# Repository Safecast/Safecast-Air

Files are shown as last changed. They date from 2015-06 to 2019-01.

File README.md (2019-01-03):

# Safecast Air

Documentation for Safecast's Air Quality Monitoring device and platform.

Parts  
https://github.com/Safecast/Safecast-Air/wiki/Assembly-Manual#parts-list

Assembly Manual  
https://github.com/Safecast/Safecast-Air/wiki/Assembly-Manual

Operation Manual  
https://github.com/Safecast/Safecast-Air/wiki/Operations-Manual

Support  
https://groups.google.com/forum/#!forum/safecast-air

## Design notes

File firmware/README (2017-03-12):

You will need the following in order to update the firmware:  

Arduino IDE 1.8.0  
https://www.arduino.cc/en/Main/Software  
  
Teensy 1.3.4 (software for version 3.2)  
https://www.pjrc.com/teensy/teensyduino.html  
  
Firmware files  
https://github.com/Safecast/Safecast-Air/tree/master/firmware  
  
For the beta we are specifically using the files from /particulate_only  
  
Look in Arduino preferences and make sure that your Arduino sketchbook location is pointing at the 'firmware' folder on your local drive. Example:
/Users/yourname/Desktop/Safecast-Air-master/firmware/  After making this change to the Arduino IDE make sure to restart the Arduino IDE.  

Programing:

1. Using the Arduino IDE open the file named particulate_only.ino which is located in the firmware/particulate_only subdirectory.

2. Go to the "Tools -> Board:"  menu item and select the board type (Teensy 3.1/3.2).

3. Go to the "Tools -> USB Type:" menu item select the  USB type (Serial). 

4. Go to the "Tools -> CPU Speed:" menu item and select the CPU speed (72MHz)

5. Go to the "Tools -> Port:" menu item and select port associated with your teensy 3.2 device e.g. COM1 (windows) or  /dev/ttyACM0 (linux)

6. Build the firmware by selecting the "Sketch -> Verify/Compile" menu item (or the "check mark" menu icon).

7. Upload the firmware to your teensy 3.2 by selecting the "Sketch -> Upload" menu item (or the "right arrow" menu icon). 

Practice  
If you are new to updating Arduino, then please go through this quick tutorial. Start with "Install Arduino" and then practice with the Blink exercise. You will then apply this same logic to upload the Safecast files.
https://www.pjrc.com/teensy/tutorial.html

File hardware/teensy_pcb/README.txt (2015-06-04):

Temporary repository for development of the safecast air prototype.

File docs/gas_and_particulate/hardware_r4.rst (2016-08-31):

Bill of Materials
===================

**This is the BOM for prototype V0.1 R4**

====================  =====  =============================================   ===================     =======================         
Ref                   Qty    Description                                     Vendor                  Part #
====================  =====  =============================================   ===================     =======================         
R1-23 (odd) [#f1]_     12     68k resistor (0.1%)                             Digikey                 YAG1958CT-ND   
R2-24 (even) [#f1]_    12     20k resistor (0.1%)                             Digikey                 P20KDACT-ND
R25                     1     22 Ohm resistor (SM0805)                        Digikey                 RMCF0805JT22R0CT-ND
R26                     1     10K resistor (SM0805)                           Digikey                 311-10KARCT-ND
R27                     1     20k resistor (SM0805)                           Digikey                 311-20.0KCRCT-ND
R28                     1     12k resistor (SM0805)                           Digikey                 311-12KARCT-ND
R29, R30                2     4.7k resistor (select via I2C requirements)     Digikey                 311-4.70KCRCT-ND
C1                      1     0.1uf ceram. cap. (SMO805)                      Digikey                 311-1361-1-ND

P1, P2 [#f1]_           2     Mini shrouded header, 5x2                       Digikey                 WM18560-ND
P3                      1     Shrouded header, 5x2                            Digikey                 S9169-ND
P4, P11                 2     2x2 pin array                                   Digikey                 609-3225-ND                 
P5,7,8,10               4     Breakaway header, male pins, 36 pos             Digikey                 3M9457-ND
P6                      1     Screw terminal block, 2-pos                     Digikey                 ED2635-ND
P9                      1     6-pin JST XH connector                          Digikey                 455-2271-ND
S1                      1     Switch, 4-direction with center push            Online components       SKQUCAA010
S2                      1     Slide switch                                    Digikey                 401-2000-ND

U1                      1     9 pos female header                             Digikey                 S7007-ND
U1                      1     Adafruit Ultimate GPS Breakout                  Adafruit                746
U2                      1     XBEE or  RN-XV WiFly                            Sparkfun                WRL-08742 or WRL-10822
U2                      2     2mm 10pin XBee Socket                           Sparkfun                PRT-08272
U3                      1     8 pos female header                             Digikey                 S7006-ND
U3                      1     Monochrome 1.3" 128x64 OLED graphic display     Adafruit                938
U4                      1     OpenLog                                         Sparkfun                DEV-09530
U5                      1     3.3V, 600mA step down voltage regulator         Pololu                  2106
U6                      1     Teensy 3.1                                      Sparkfun                DEV-12646
U6                      1     Teensy header                                   Digikey                 WM17453-ND
U6                      2     14 pos female header                            Digikey                 S7012-ND
U6                      2     5 pos female header                             Digikey                 S6103-ND
U6                      2     7 pos female header                             Digikey                 S7005-ND
U7                      1     Resistor array, isolated                        Digikey                 4608X-2-102LF-ND
U8                      1     Schmitt buffer                                  Digikey                 TC7SZ17FU(T5LJFTCT-ND
U9                      1     Adafruit temperature humidity breakout          Adafruit/Digikey        2857/1528-1540-ND
Q1                      1     P-Channel MOSFET (SOT-323)                      Digikey                 DMP2160UWDICT-ND
====================  =====  =============================================   ===================     =======================         

.. rubric:: Footnotes

.. [#f1] These components are not required for particulate only board.

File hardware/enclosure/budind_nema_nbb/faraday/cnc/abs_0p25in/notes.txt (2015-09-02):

Machining operations  (CNC router)

1. fixture_drill.ngc (part secured with double sided type)

-------------------------------------------------
Secure material with #6 screws via fixture holes
-------------------------------------------------

2. pocket_hole.ngc

3. sensor_cutout.ngc

------------------------------------------------
Secure parts etc. with #6 screws
------------------------------------------------

4. boundary.ngc

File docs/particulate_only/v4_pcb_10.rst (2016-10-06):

Teensy board
====================

Take the Teensy header and solder onto the Teensy board as shown in the image below.

The teensy header is the one with two rows of seven pins with flat foot terminals.  Solder it to the Teensy board by placing the board solder side up with the board flat.  Locate the teensy header over the solder pads centering the feet over the pads.  Solder one end terminal to secure the header, check the alignment then reposition if required by reheating the end terminal.  Once the alignment is correct solder the remaining terminals.

Complete the assembly by installing two 14 pin terminals one the sides, 5 pin terminal on the end and finally one modified 5 pin terminal (remove the second pin by simply pulling it out of the assembly) adjacent to the upper most 14 pin terminal in the photo.

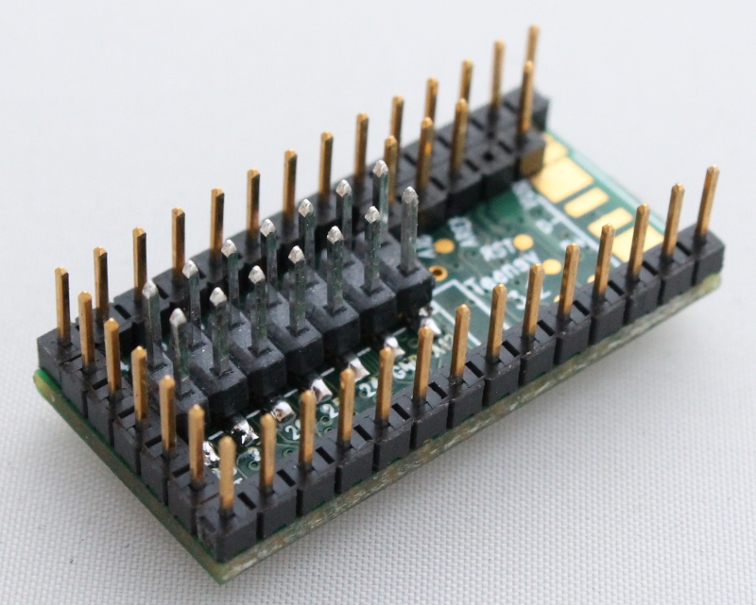
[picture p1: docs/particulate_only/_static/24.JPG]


Place the Teensy board into the female headers as shown below.

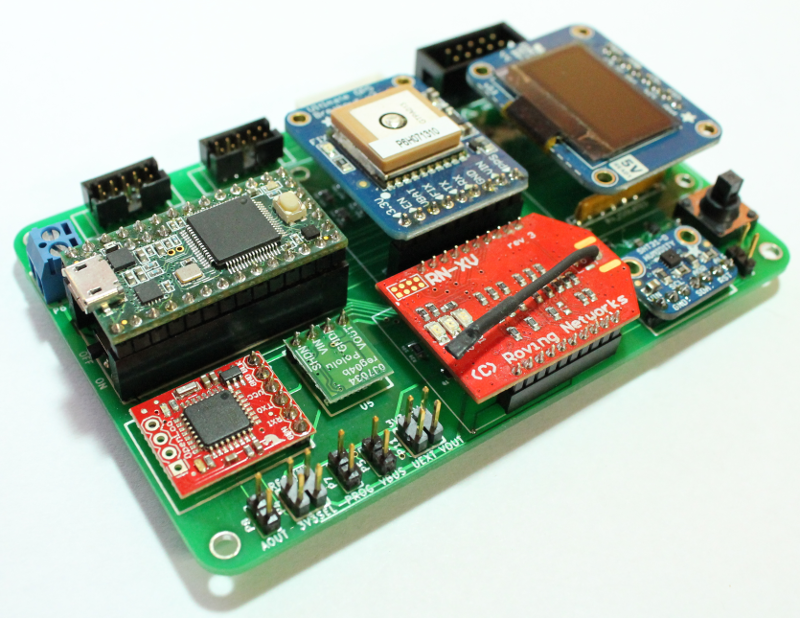
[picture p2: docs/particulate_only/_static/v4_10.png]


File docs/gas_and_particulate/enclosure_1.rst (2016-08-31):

Enclosure
-------------------

Images of enclosure with Safecast Air board and methane sensor

|

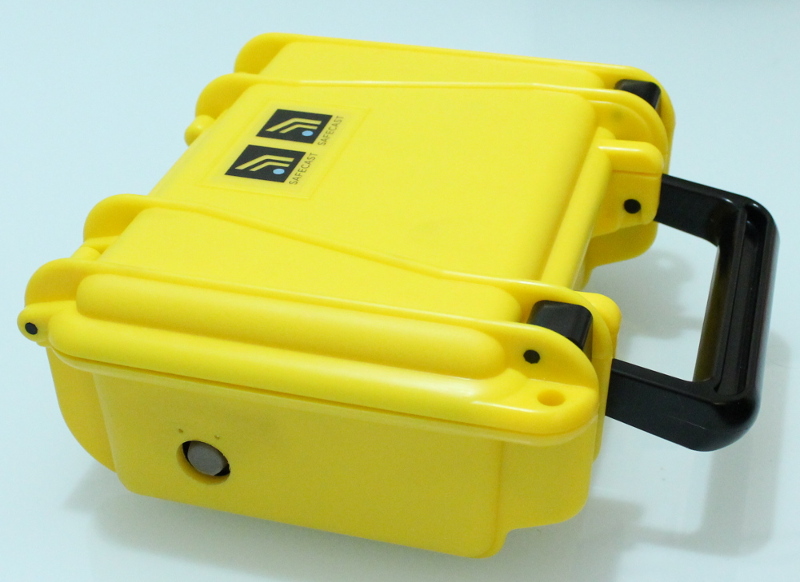
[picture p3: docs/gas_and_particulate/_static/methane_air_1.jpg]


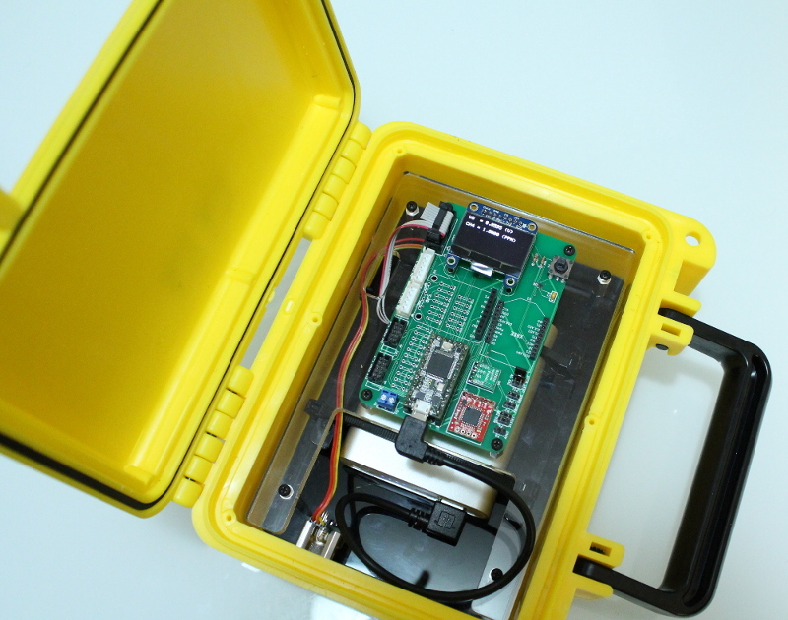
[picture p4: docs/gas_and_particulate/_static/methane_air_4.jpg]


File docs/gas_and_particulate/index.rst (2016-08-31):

.. Safecast documentation master file, created by
   sphinx-quickstart on Mon Apr 27 13:28:54 2015.
   You can adapt this file completely to your liking, but it should at least
   contain the root `toctree` directive.

Safecast Air Prototype
====================================

This is the project documentation for the Safecast Air Board. Includes the parts lists and build instructions for making a Safecast Air Board. 



Features
----------------

* Configurable air quality measurement board. Can be used as a Single or multi-sensor configurations. 
* On-board temperature/humidity sensor
* Based on Teensy 3.x development board
* On-board GPS for location data (similar to the Safecast radiation sensor)
* On-board WiFi for sending real-time data to Safecast server
* Two designated headers for using up to six Alphasense 4-electrode gas sensors (both A4 and/or B4 types)
* Designated header for Alphasense Particulate Monitor (OPC-N2)
* UEXT expansion header for connecting other additional sensors or other hardware e.g. methane sensor
* SD card (OpenLog) for data storage
* LCD display
   
The Safecast Air board is an **Open Source Hardware** project. KiCad design files for the PCB can be found on Github: https://github.com/Safecast/Safecast-Air.  

Table of Contents
----------------------

.. toctree::
   :maxdepth: 1

   toc.rst

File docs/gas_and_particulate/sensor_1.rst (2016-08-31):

Alphasense Air Sensors (A4)
================================

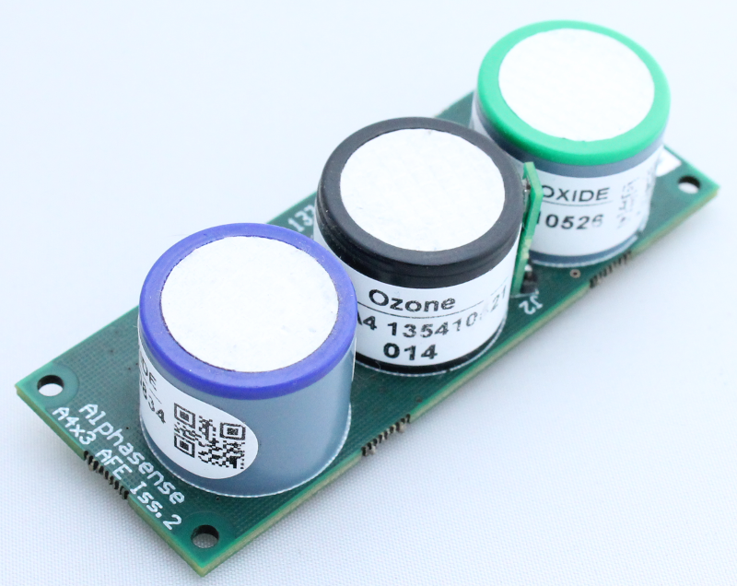
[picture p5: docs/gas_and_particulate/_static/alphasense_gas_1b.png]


|

* These are the A4 small (20mm) Alphasense AFE gas sensors mounted in a A4 x 3 configuration
* Available for measuring several gases including carbon monoxide, ozone, nitric oxide and more
* More information on the A4 air quality sensors can be found on the Alphasense website: http://www.alphasense.com/index.php/air/products/

Connecting to the Safecast Air Board
-------------------------------------------

Ribbon Cable
^^^^^^^^^^^^^^^^^^^^^^^

* Flat ribbon cable, 1 mm pitch, 10 conductor e.g. Digikey Part # MC10L-5-ND. 
* 10 pos, 2 mm pitch cable connector on each end of the ribbon cabble. Digikey part # WM14310-ND.

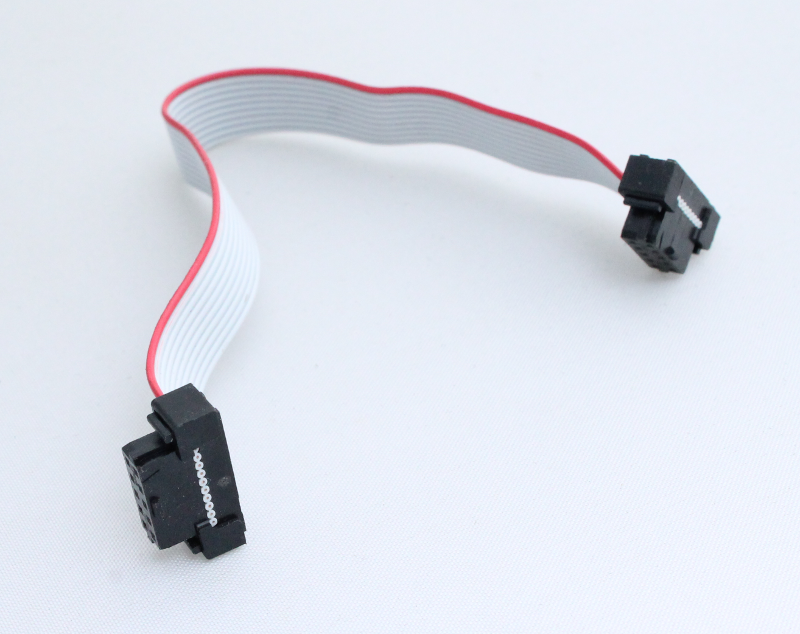
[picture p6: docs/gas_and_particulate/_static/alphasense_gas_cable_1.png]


|

* Connect the ribbon cable to the header on the back of the air sensor board

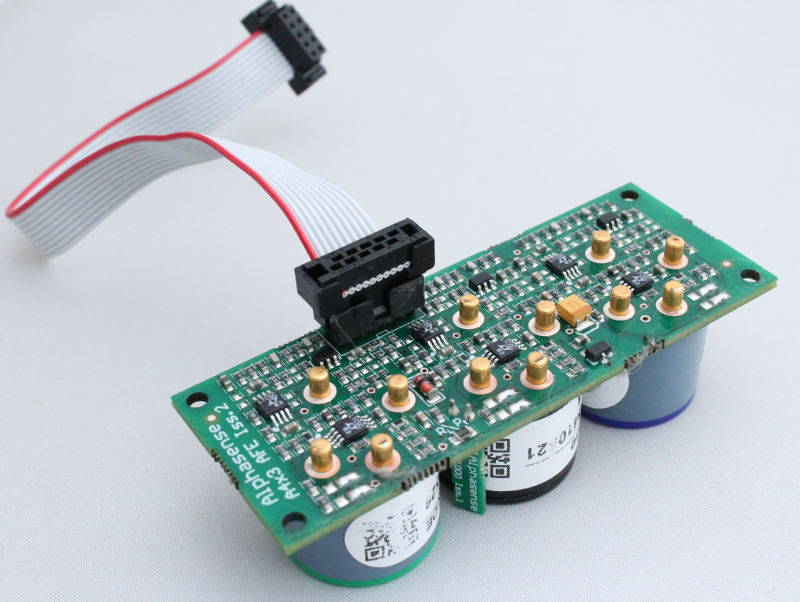
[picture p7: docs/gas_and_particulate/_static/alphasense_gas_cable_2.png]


|

* The Safecast Air Board includes two designated headers (P1 and P2) for the Alphasense air sensors. 
* Connect the ribbon cable to one or both of these headers as shown below

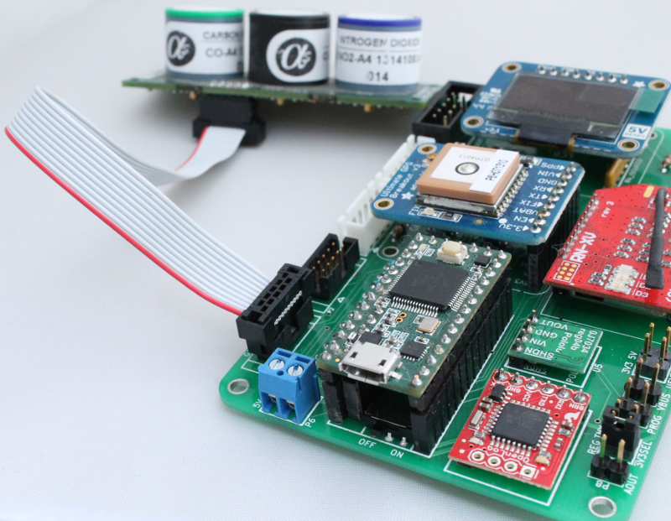
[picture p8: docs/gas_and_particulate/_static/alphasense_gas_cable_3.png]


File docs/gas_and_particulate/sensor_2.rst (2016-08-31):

Alphasense Individual Sensor Boards (B4)
============================================

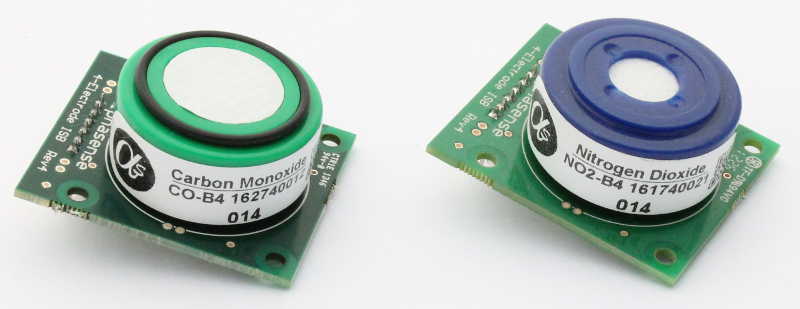
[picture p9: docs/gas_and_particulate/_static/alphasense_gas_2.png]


|

* These are the larger B4 size (32mm) Individual Sensor Board (ISB) from Alphasense
* Like the smaller A4 type, these are also available for measuring several gases including carbon monoxide, ozone, nitric oxide and more
* More information on the A4 air quality sensors can be found on the Alphasense website: http://www.alphasense.com/index.php/air/products/

Safecast ISB Adaptor Board
-------------------------------------------

* Use the Safecast ISB Adaptor Board to connect up to 3 of the B4 sensors to the Safecast Air board
* ISB Adaptor Board also includes a temperature sensor

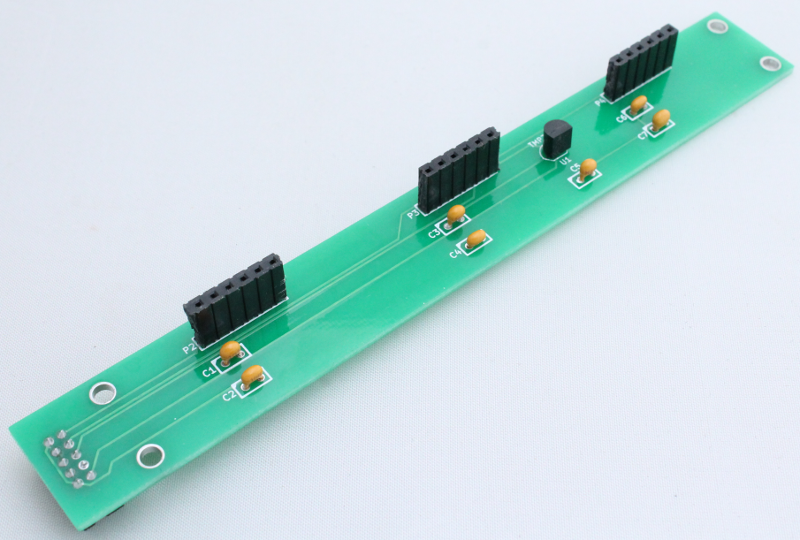
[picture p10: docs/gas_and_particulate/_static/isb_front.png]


ISB Adaptor Board BOM
^^^^^^^^^^^^^^^^^^^^^^^^^^^

=============  =====  =============================================   ===================     =======================         
Ref            Qty    Description                                     Vendor                  Part #
=============  =====  =============================================   ===================     =======================         
P1              1      Mini shrouded header, 5x2                       Digikey                 S68KCACT-ND
P2,3,4          1      Breakaway header, female, 36 pos                Digikey                 929974E-01-36-ND
C1,3,5          3      10 nF                                           Digikey                 399-9858-1-ND
C2,4,6,7        4      100 nF                                          Digikey                 399-4151-ND
U1              1      Temperature Sensor                              Digikey                 TMP36GT9Z-ND
=============  =====  =============================================   ===================     =======================         
 
Connecting to the Safecast Air Board
------------------------------------------
 
* Mount up to 3 of the sensors to the Safecast ISB Adaptor Board
 
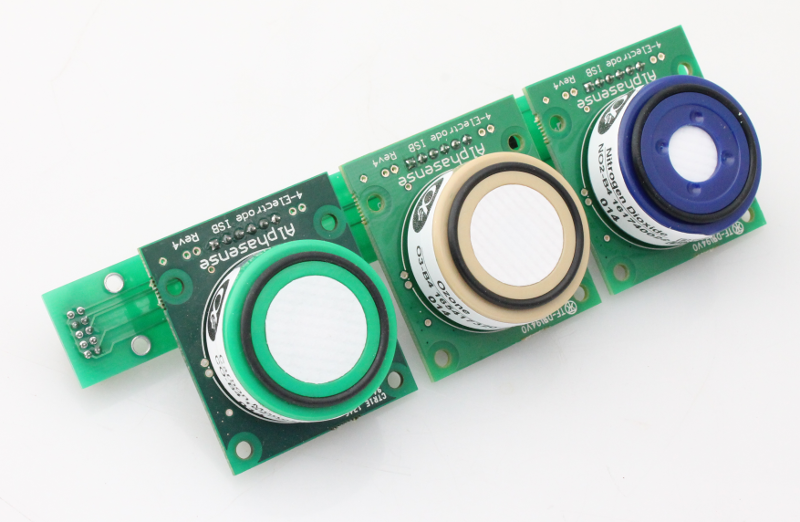
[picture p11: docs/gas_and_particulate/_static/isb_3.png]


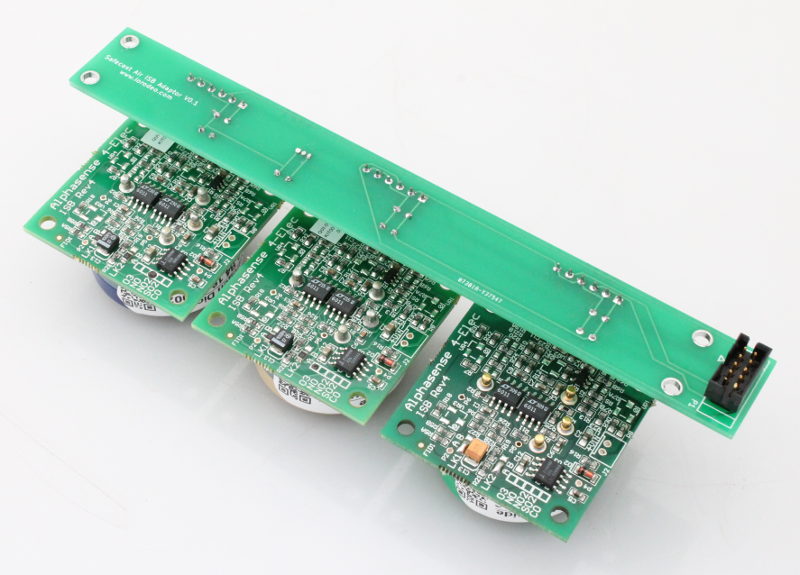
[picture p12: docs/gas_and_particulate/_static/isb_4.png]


|

* The Safecast Air Board includes two designated headers (P1 and P2) for the Alphasense air sensors. 
* Using the same connector ribbon cable as described on the previous page, connect the ribbon cable to the back of the ISB Adaptor board and the P1 and/or P2 header on the Safecast Air Board.

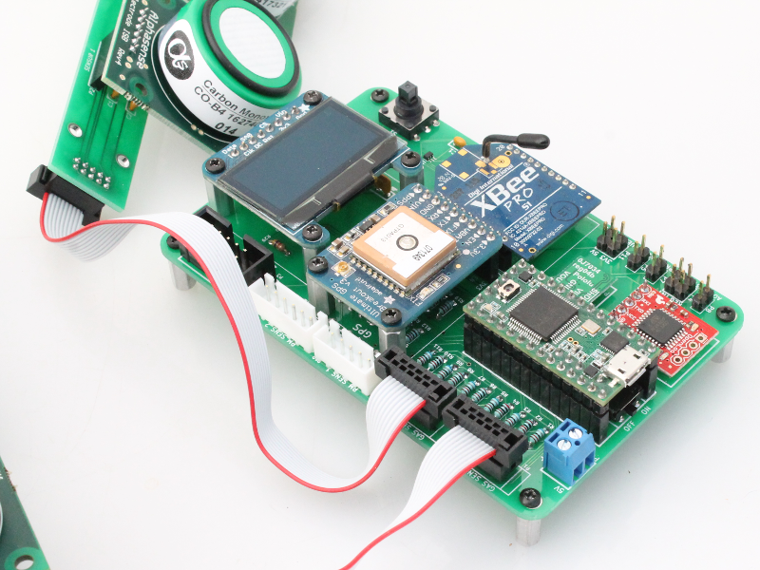
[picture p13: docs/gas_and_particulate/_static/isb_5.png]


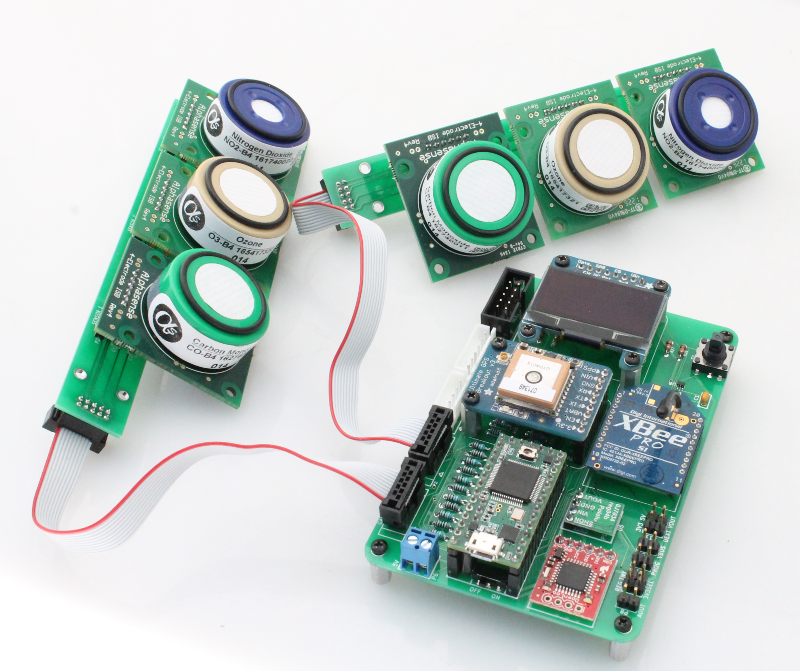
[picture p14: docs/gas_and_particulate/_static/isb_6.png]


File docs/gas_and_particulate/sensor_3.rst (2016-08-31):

Alphasense Particulate Monitor (OPC-N2)
==========================================

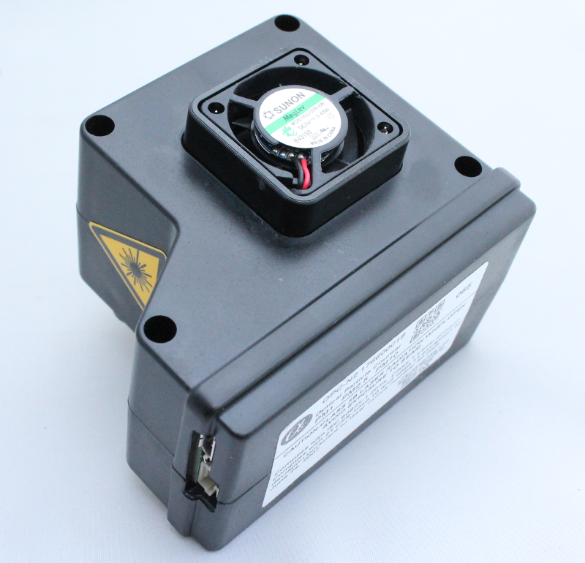
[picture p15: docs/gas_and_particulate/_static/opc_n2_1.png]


|

* The Optical Particle Monitor (OPC-N2) measure PM1, PM2.5 and PM10. 
* More information on the Particulate Sensor can be found on the Alphasense website: http://www.alphasense.com/index.php/products/optical-particle-counter/

OPC-N2 Custom cable
----------------------------------------

Make a custom cable for connecting the Particulate monitor to the board

=====  =============================================   ===================     =======================         
Qty    Description                                     Vendor                  Part #
=====  =============================================   ===================     =======================         
1      Wire, 28 AWG, Black                              Digikey                 W2628B-50-ND
1      Connector recept, 6 pos, 1 mm                    Digikey                 WM7919-ND
6      Terminal crimp for use with 1mm connector        Digikey                 WM7933-ND
1      Connector recept, 6 pos, 2.5 mm                  Digikey                 455-2218-ND
6      Terminal crimp for use with 2.5 mm connector     Digikey                 455-2261-1-ND
=====  =============================================   ===================     =======================         

Other tools you will need to make the cable: hand crimp e.g. Molex hand crimp.

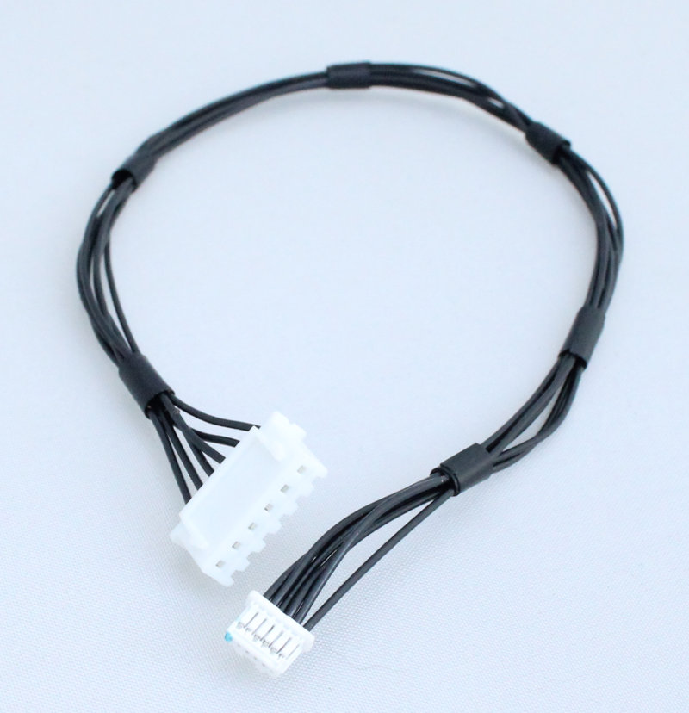
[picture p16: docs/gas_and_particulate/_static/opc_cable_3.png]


Connecting to the board
----------------------------

* The Safecast Air Board has a designated header (P9) for the OPC-N2 particulate monitor. 
* Connect the OPC-N2 custom cable to the front of the OPC-N2 monitor and the P9 header on the Safecast Air Board.

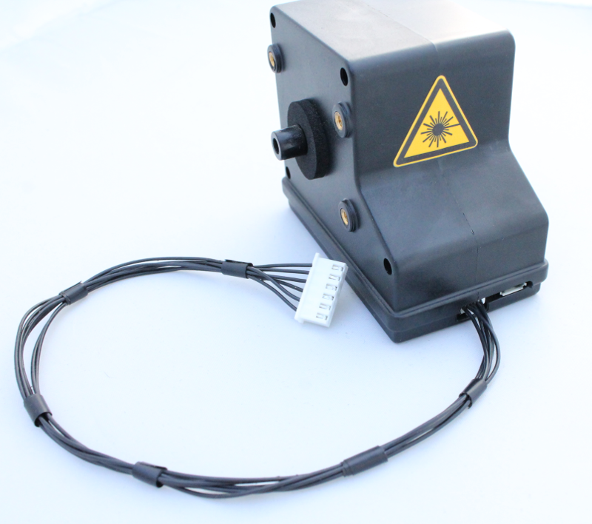
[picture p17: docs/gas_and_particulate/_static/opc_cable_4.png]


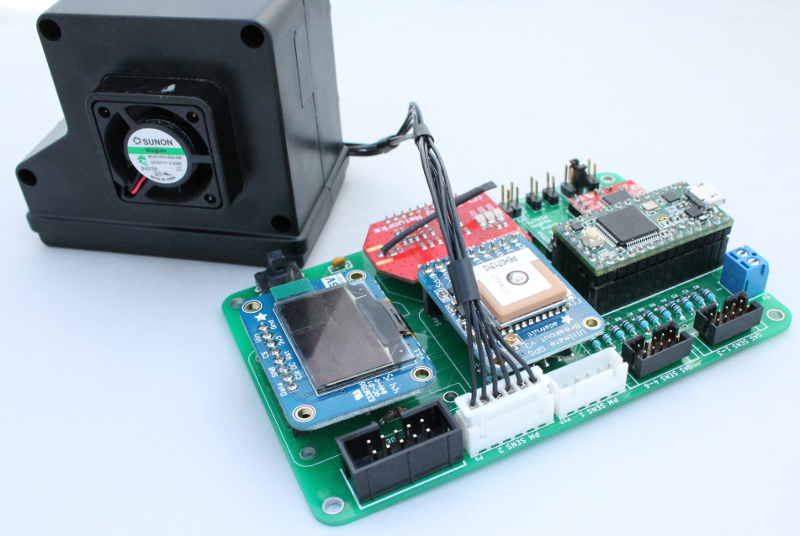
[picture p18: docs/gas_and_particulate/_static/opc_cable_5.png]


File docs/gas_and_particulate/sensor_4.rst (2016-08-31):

Pololu Methane Sensor
==============================

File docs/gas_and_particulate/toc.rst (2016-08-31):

Table of Contents
=======================

Safecast Air Board (v0.1 R4)
---------------------------------------------

.. toctree::
   :maxdepth: 2

   version_4.rst
   hardware_r4.rst

Build Instructions
------------------------------

.. toctree::
   :maxdepth: 2

   v4_pcb_1.rst
   v4_pcb_2.rst
   v4_pcb_3.rst
   v4_pcb_4.rst
   v4_pcb_5.rst
   v4_pcb_6.rst
   v4_pcb_7.rst
   v4_pcb_8.rst
   v4_pcb_9.rst
   v4_pcb_9b.rst
   v4_pcb_10.rst

Connecting sensors to the board
--------------------------------------

.. toctree::
   :maxdepth: 2

   sensor_1.rst
   sensor_2.rst
   sensor_3.rst
   sensor_4.rst

Building the enclosure
-----------------------------

.. toctree::
   :maxdepth: 2

   enclosure_1.rst

Previous board versions
--------------------------------------------------------

.. toctree::
   :maxdepth: 1

   version_3.rst

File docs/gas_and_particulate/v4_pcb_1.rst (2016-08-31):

Reflow soldering SMT components
===================================================

There are several surface mount (SMT) components in the kit. These should be soldered onto the board first before the through-hole components. For this step you will need solder paste and tweezers. We use a toaster oven for reflow soldering.
If you are new to reflow soldering, there are online resources and tutorials. 

Overview of steps
---------------------

* Place a small amount of solder paste onto the pads for the component you are working on
* Use tweezers to pick up, place and align the component onto the solder paste
* If necessary, use a magnifying lens to check the component placement on the board
* Repeat steps for all components before reflow soldering 
* Once all of the components below are placed you can begin reflow soldering 

Voltage divider resistors for the alphasense 4-electrode gas sensors
-------------------------------------------------------------------------- 

R1-R23 odd-numbered resistors (68K) and R2-R24 even-numbered resistors (20K) are paired. For example, R1 & R2 are paired, R3 & R4 etc. Each resistor pair is for one of the 12 analog inputs. The resistor pair form a voltage divider for scaling 0-5V sensor output to 0-1.2V analog input range (using 1.2V internal reference voltage).

* 20K (0.1%) resistors (R2,4,6,8,10,12,14,16,18,20,22,24)
* 68K (0.1%) resistors (R1,3,5,7,9,11,13,15,17,19,21,23)

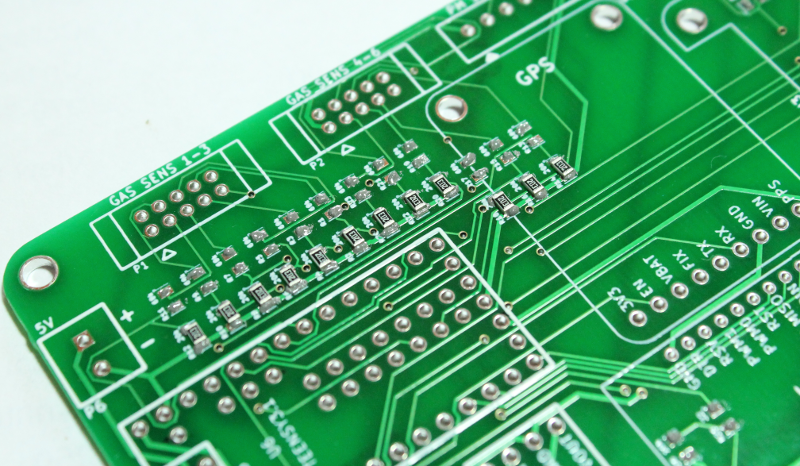
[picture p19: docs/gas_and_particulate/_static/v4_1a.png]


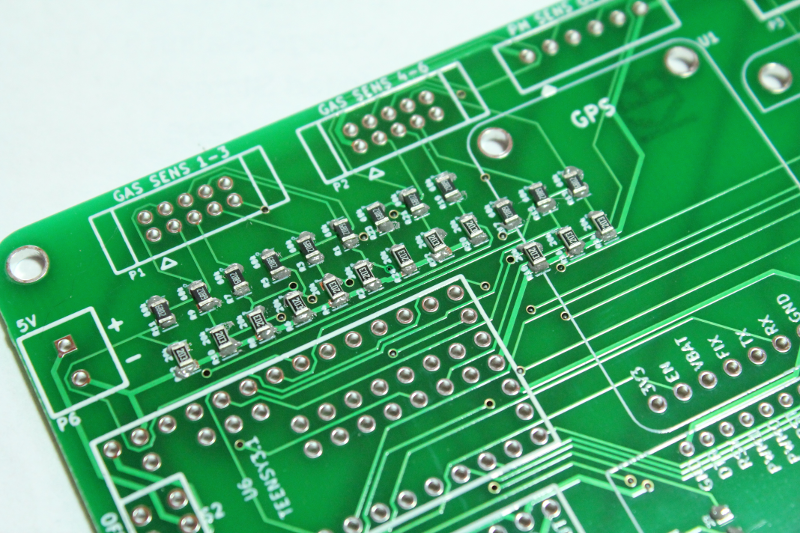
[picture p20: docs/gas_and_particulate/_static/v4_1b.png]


MOSFEFT power switch components
--------------------------------------------

* P-Channel MOSFET (Q1)
* 22 Ohm resistor (R25) 
* 10K resistor (R26) 

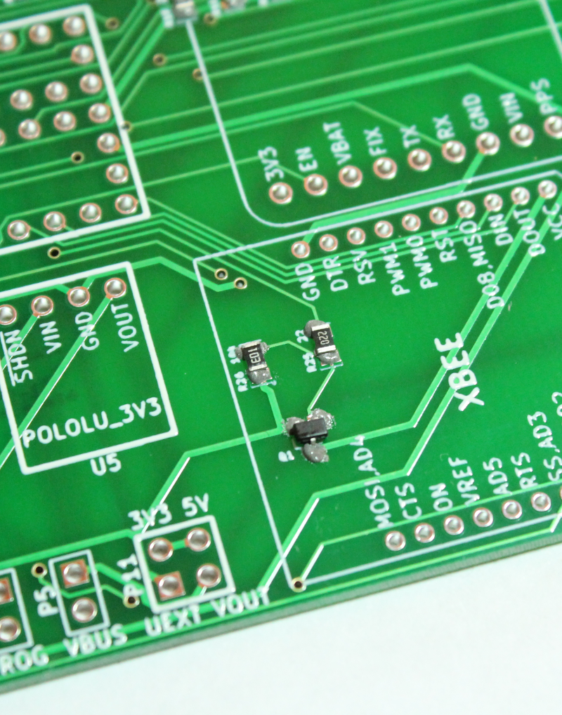
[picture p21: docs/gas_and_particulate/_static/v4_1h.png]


Circuity for toggle switch
----------------------------
 
* 20K Resistor (R27)
* 12K Resistor (R28)
* 0.1 uF capactor (C1) 
* Schmitt buffer (U8)

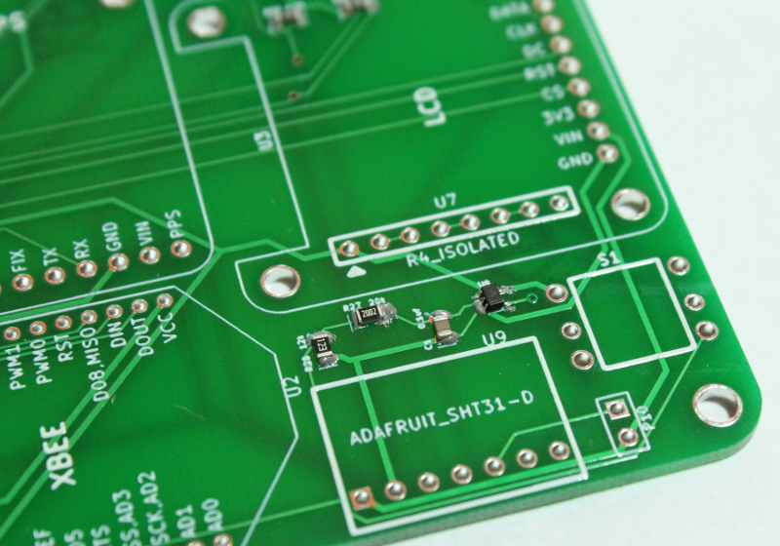
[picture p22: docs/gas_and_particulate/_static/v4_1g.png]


I2C pull-up resistors
------------------------------------------

* 4.7K resistors (R29 and R30) 

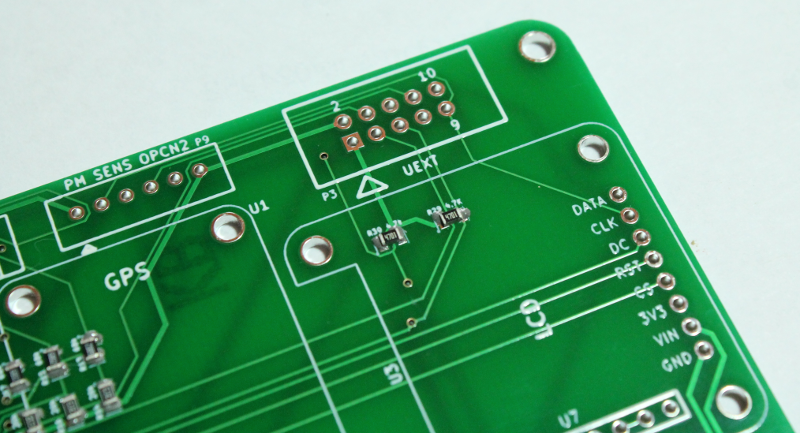
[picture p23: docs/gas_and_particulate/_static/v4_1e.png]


After the last components have been placed, the board is ready to go into the reflow oven. This usually takes aapprox. 5 mins.

Images of the board after reflow soldering
--------------------------------------------

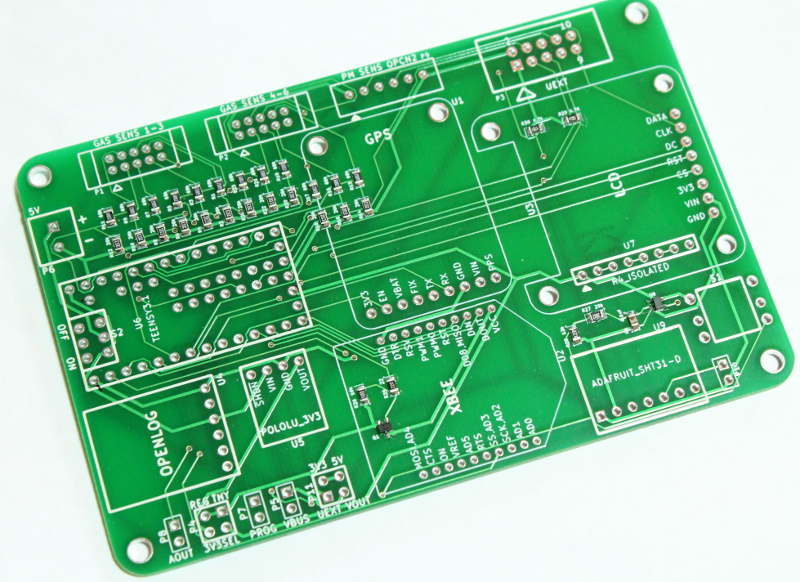
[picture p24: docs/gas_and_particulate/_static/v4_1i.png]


|



|



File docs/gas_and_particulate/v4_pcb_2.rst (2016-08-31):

Joystick input circuit
===================================

A 5-position joystick toggle switch is used for accessing device configuration menus. It is not yet enabled in firmware. 
A resistor array (U7) is also required. 

* Solder the toggle switch and resistor array onto the board as shown in the pictures below. 





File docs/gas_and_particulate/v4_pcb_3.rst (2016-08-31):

External 5V power  
=================================

Optional source of higher current power input which can be used as an alternative to powering from the USB connector on the Teensy (500 mA limit). The slide switch (S2) can be used as an on/off switch for the device when using the external 5V power. 

* Solder the blue 2-position terminal block onto the board as shown below. Make sure the terminal block is positioned with the connector side facing out.
 


* Solder the switch onto the board as shown below.



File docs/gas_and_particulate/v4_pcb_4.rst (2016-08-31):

Headers for gas and particulate sensors
==============================================

There are 4 headers for connecting sensors to the board. **For a particulate-only board, you can skip Headers P1 and P2.** 

* P1 and P2 - Connecting the Alphasense Gas sensor headers 
* P9 - Connecting the Alphasense OPC-N2 particulate sensor 
* P3 - UEXT general purpose expansion header. Has 12C, SPI and UART. Can also be used as additional analog inputs e.g. for connecting methane sensor.



* Solder the headers onto the board as shown in the images below.
   


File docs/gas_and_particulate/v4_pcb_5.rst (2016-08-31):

Configuration and expansion headers
===========================================

These pins provide access to additional features on the Teensy and some additional configuration options for the device.

* AOUT (P8) - This header provides access to the onboard DAC (digital to analog converter) on the Teensy.  
* 3V3SEL (P4) - Selects between the 3.3V regulator on the Teensy or the higher current external 3.3V Pololu regulator. You might use the higher current Pololu regulator when using the XBEE or WiFly.
* PROG (P7) - Provides access to the Teensy program signal which reboots the microcontroller into Bootloader mode. (Development option).
* VBUS (P5) - For connecting the external power to the Teensy. If you are using the external power you will want to put a jumper on the pins.
* UEXT VOUT (P11) - Selects the power for the UEXT expansion header, whether it is 5V or 3.3V. For example, to select 5V, place a jumper on the right pins.

The kit includes a 36-position male breakaway header and two of the 2x2 pin headers. Take the brekaway header and carefully snap off 3 sets of 2-position headers. 



* Solder the 2x2 pins into positions P4 and P11.
* Solder the 2x1 headers into positions P5, P7 and P8. Solder with the longer pin facing up. 



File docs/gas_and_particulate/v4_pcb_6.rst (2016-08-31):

Solder Pin Headers
===================================

* Take the same breakaway header from the previous step and break off a 4-pin, 6-pin header, 2-pin and 7-pin header. 



|

* Solder the 6-pin and 4-pin into positions U4 and U5 as shown in the image below. **Solder with the shorter pin side facing up.** These pin headers will be used to connect the OpenLog SD card data logger and Pololu 3V3 optional power regulator later in the instructions. 


   
|
   
* Solder the 7-pin header into position U9 as shown in the image below. **Solder with the shorter pin side facing up.** This pin header will be used to connect the Adafruit temp/humidity sensor later in the instructions.
* Solder the 2-pin header into position P10. For this header, **solder with the longer pin side facing up.** This pin header can be used with a jumper to change the I2C address of the Adafruit temp/humidity sensor in the event of a conflict with an optional device on the UEXT header. 



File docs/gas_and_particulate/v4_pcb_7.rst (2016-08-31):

Teensy Headers
================================

Use the pairs of 5-position, 7-pos and 13-pos female headers in the kit to build up a Teensy header on the board. 

* Start with one of the 5-pos headers. Use wire clippers to cut off the second pin leg (this is not shown in the image). 
* Place this onto the board and solder in place. 
* Continue to build up the rest of the headers using the images below as a guide.
* These female headers will be used to connect the Teensy later in the instructions. 





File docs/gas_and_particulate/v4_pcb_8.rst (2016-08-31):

GPS, LCD and XBEE Headers
==================================

This step also involves soldering the same type of female headers onto the board. 

* Solder a 9-pos feamle header into U1 
* Solder a 8-pos feamle header into U3 
* These female headers will be used to connect the Adafruit Ultimate GPS Breakout, Adafruit OLED graphic display later in the instructions. 


   
|   

* Take the two 10-position XBEE headers. These are shorter headers than the ones used in the previous steps. 
* Solder these into the board at position U2 
* These female headers will be used to connect the XBEE RF module or Sparkfun RN-XV WiFly later in the instructions. 



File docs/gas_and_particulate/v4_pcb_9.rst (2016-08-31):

Soldering components
=====================================

In this step, place the following three components onto the pins which were placed earlier. These components are then soldered onto the pins.  
   
AdaFruit Temp/Humidity Sensor
----------------------------------

Place the Temp/Humidity sensor onto the 7-pin header and solder in place as shown in the image below.



OpenLog SD card data logger
----------------------------------

Place the OpenLog onto the 6-pin header and solder in place as shown in the image below.



Pololu 3V3  power regulator
----------------------------------

Place the Pololu 3V3 module onto the 4-pin header and solder in place as shown in the image below.



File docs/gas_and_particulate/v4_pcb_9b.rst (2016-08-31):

Placing GPS, XBEE and display
=============================================

In this step, place the following three components into the female headers which were placed earlier. These components are not soldered, as the pins on the components are instead pushed into the headers.  

Adafruit Ultimate GPS Breakout
^^^^^^^^^^^^^^^^^^^^^^^^^^^^^^^^^^^^

Adafruit GPS Breakout board comes with a 9-pin array. Solder this onto the breakout board as shown in the images below.
   


Insert the GPS board into the 9-position female header as shown in the image below.



XBEE/WiFly wireless communication module
^^^^^^^^^^^^^^^^^^^^^^^^^^^^^^^^^^^^^^^^^^^^^

Insert the XBEE RF module or Sparkfun RN-XV WiFly into the sockets as shown in the image below. 
   


Adafruit OLED graphic display
^^^^^^^^^^^^^^^^^^^^^^^^^^^^^^^^^^^^

The Adafruit graphic display comes with an 8-pin array. Solder this onto the board as shown in the image below and insert the LCD display into the 8-position female header.


   


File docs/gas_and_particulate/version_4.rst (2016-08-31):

Notes on changes to version r4
==================================

Below is a layout image for the most recent board (ver 0.1 rev 4). 



Safecast V0.1 R4 Change notes
-----------------------------------

#. Removed header for Amphenol/Shinyei particle sensor. Note, this type of sensor could still be connected to the UEXT header if someone wants to use this type of sensor - we just removed the dedicated header for this.

#. Disconnected pin D33. This pin can be problematic if state can't be guaranteed at Teensy start up. This pin was used for SPI CS line on UEXT and wifly/XBEE/Lora header. New version is now using pin D32 for the CS line.   

#. Added on-board temperature and humidity sensor (I2C).  This way the device will always have temperature and humidity regardless of sensor configuration (single sensor, multi-sensor, etc). In previous versions the only temperature sensors were on the gas sensor adaptor boards - so the device only had temperature measurements when the gas sensors were connected.    

#. Added mosfet switch for controlling power to wifly/XBEE using IO pin on the Teensy. This way the Teensy can toggle the power to the Wifly if it detects that there is an issue e.g. it is unresponsive. 

#. Replaced some of the existing through-hole components - resistors, capacitors - with surface mount components. This makes layout easier. Used the larger of the surface mount packages e.g. SM0805. 

#. Added the Safecast logo to the silkscreen (back).

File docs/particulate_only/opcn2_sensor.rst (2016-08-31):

Alphasense Particulate Monitor (OPC-N2)
==========================================



|

* The Optical Particle Monitor (OPC-N2) measure PM1, PM2.5 and PM10. 
* More information on the Particulate Sensor can be found on the Alphasense website: http://www.alphasense.com/index.php/products/optical-particle-counter/

OPC-N2 Custom cable
----------------------------------------

The kit will include a pre-made custom cable for connecting the OPC-N2 particulate monitor to the Safecast Air board. You will not be required to make this cable.
In intial protypes we were making these cables and have included the instructions below for informational purposes only. 

=====  =============================================   ===================     =======================         
Qty    Description                                     Vendor                  Part #
=====  =============================================   ===================     =======================         
1      Wire, 28 AWG, Black                              Digikey                 W2628B-50-ND
1      Connector recept, 6 pos, 1 mm                    Digikey                 WM7919-ND
6      Terminal crimp for use with 1mm connector        Digikey                 WM7933-ND
1      Connector recept, 6 pos, 2.5 mm                  Digikey                 455-2218-ND
6      Terminal crimp for use with 2.5 mm connector     Digikey                 455-2261-1-ND
=====  =============================================   ===================     =======================         

Other tools you will need to make the cable: hand crimp e.g. Molex hand crimp.



Connecting to the board
----------------------------

* The Safecast Air Board has a designated header (P9) for the OPC-N2 particulate monitor. 
* Connect the OPC-N2 custom cable to the front of the OPC-N2 monitor and the P9 header on the Safecast Air Board.





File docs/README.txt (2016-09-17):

Sphinx source for Safecast-Air documentation. Note, if you just want to
read the documentation see https://safecast.github.io/Safecast-Air 

1. The documentation for the particulate only version of the sensor can be
   found in the "particulate_only" sub-directory.

2. The documentation for the gas and particulate version of the sensor can be
   found in the "gas_and_particulate" sub-directory.

3. The documentation is created using Sphinx documentation tool. 
   http://www.sphinx-doc.org/en/stable/index.html 

4. A reasonably recent version of sphinx (>= v1.2.2) is required to build the
   html or pdf  versions of the documentation from the restructured text (.rst)
   source files. Installation instructions for Sphinx can be found here 
   http://www.sphinx-doc.org/en/stable/install.html

5. To build the html version of the documentation run "make html" from inside
   the documentation sub-directory - i.e. either the "particulate_only" or
   "gas_and_particulate".  The documentation will be created in a sub-directory
   named "_build/html".

6. To build the pdf version of the documentation a working version of latex is
   required https://www.latex-project.org/.  First run "make latex" in the 
   documentation sub-directory - i.e. either "particulate_only" or
   "gas_and_particulate". A latex verion of the documentation will be
   created in the "_build/latex" sub-directory. A pdf can then be generated
   by running "make" in the "_build/latex" sub-directory.

7. To clean the project directories (if desired) run "make clean".   Note,
   this will remove all generated documenation and intermediary files.



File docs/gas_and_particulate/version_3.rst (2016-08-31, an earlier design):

Version 3.0
=========================

Image of Prototype V0.1 R3 
------------------------------



Bill Of Materials
--------------------
   
**This is the BOM for prototype V0.1 R3 shown above**

=============  =====  =============================================   ===================     =======================         
Ref            Qty    Description                                     Vendor                  Part #
=============  =====  =============================================   ===================     =======================         
R1-23 (odd)    12     68K resistor (1%)                               Digikey                 S68KCACT-ND
R2-24 (even)   12     20K resistor (1%)                               Digikey                 S20KCACT-ND
R25,R26        2      10k resistor                                    Digikey                 S10KQCT-ND
R27            1      20K resistor                                    Digikey                 S20KQCT-ND
R28            1      12k resistor                                    Digikey                 S12KQCT-ND
R29,R30        2      4.7k resistor (select via I2C requirements)     Digikey                 S4.7KQCT-ND     
C1             1      0.1uf ceramic capacitor                         Digikey                 399-4151-ND

P1, P2         2      Mini shrouded header, 5x2                       Digikey                 WM18560-ND
P3             1      Shrouded header, 5x2                            Digikey                 S9169-ND
P4, P11        2      2x2 pin array                                   Digikey                 609-3225-ND                 
P5,7,8         3      Breakaway header, male pins, 36 pos             Digikey                 3M9457-ND
P6             1      Screw terminal block, 2-pos                     Digikey                 ED2635-ND
P9             1      6-pin JST XH connector                          Digikey                 455-2271-ND
P10            1      5-pin JST XH connector                          Digikey                 455-2270-ND 
S1             1      Switch, 4-direction with center push            Online components       SKQUCAA010
S2             1      Slide switch                                    Digikey                 401-2000-ND

U1             1      Adafruit Ultimate GPS Breakout                  Adafruit                746
U2             1      XBEE                                            Sparkfun                WRL-08742
(or            1      RN-XV WiFly                                     Sparkfun                WRL-10822) 
U2             2      2mm 10pin XBee Socket                           Sparkfun                PRT-08272
U3             1      Monochrome 1.3" 128x64 OLED graphic display     Adafruit                938
U4             1      OpenLog                                         Sparkfun                DEV-09530
U5             1      3.3V, 600mA step down voltage regulator         Pololu                  2106
U6             1      Teensy 3.1                                      Sparkfun                DEV-12646
U6             1      Teensy header                                   Digikey                 WM17453-ND
U1,3,6         3      Breakaway header, female, 36 pos                Digikey                 929974E-01-36-ND
U7             1      Resistor array, isolated                        Digikey                 4608X-2-102LF-ND
U8             1      Schmitt buffer                                  Digikey                 TC7SZ17FU(T5LJFTCT-ND
=============  =====  =============================================   ===================     =======================         

Build instructions 
==================================

1) Resistors
-----------------------

Voltage divider resistors for the alphasense 4-electrode gas sensors
^^^^^^^^^^^^^^^^^^^^^^^^^^^^^^^^^^^^^^^^^^^^^^^^^^^^^^^^^^^^^^^^^^^^^^^^^^^^^^^^

* R1-R23 odd-numbered resistors (68K) and R2-R24 even-numbered resistors (20K) are paired. For example, R1 & R2 are paired, R3 & R4 etc.
* Each resistor pair is for one of the 12 analog inputs.
* The resistor pair form a voltage divider for scaling 0-5V sensor output to 0-1.2V analog input range (using 1.2V internal reference voltage).

Take the 68K resistors are solder these into each of the 12 odd-numbered positions from R1-R23 i.e. R1,3,5,7,9,11,13,15,17,19,21 and 23.



Next, take the 20K resistors are solder these into each of the 12 even-numbered positions from R2-R24 i.e. R2,4,6,8,10,12,14,16,18,20,22 and 24.



Pull-up resistors 
^^^^^^^^^^^^^^^^^^^^^^^^^^^^^^^^^^^^^^^^^^^^^^^^^^^^^^^^^^^^^^^^^^^^^^^^^^^^^^^^

* R25 and R26 are pull-up resistors for the amphenol particulate sensor (P10). Note, these will be likely removed in the next board revision.
* R29 and R30 are I2C pull-up resistors for the UEXT header 

Solder these resistors to the board as shown in the image below.



2) Joystick input circuit
-------------------------------------

A 5-position joystick toggle switch is used for accessing device configuration menus. It is not yet enabled in firmware.

In addition to the toggle switch (S1) the following additional components are required for the joystick circuit:

* 20K Resistor (R27)
* 12K Resistor (R28)
* 0.1 uF capactor (C1) 
* Resistor array (U7) 
* Schmitt buffer (U8)

Solder the resistors and capacitors onto the board as shown in the pictures below (no specific order). 



Solder the toggle switch onto the board.



Solder the Schmitt buffer onto the board (image to be added).

3) Headers for gas, particulate sensors
-----------------------------------------------------

Sensor Headers
^^^^^^^^^^^^^^^^^^^^^^^^^^^^^^^^^^^^^^^^^^^^^^^^^^^^^^^^^^^^^^^^^^^^^^^^^^^^^^^^

There are 5 headers available for connecting sensors to the board. 

* **P1 and P2** - Alphasense Gas sensor headers 
* **P9** - OPC-N2 Alphasense particulate sensor 
* **P10** - Amphenol particulate sensor. In the next board revision P10 will be removed and the digital lines can be used for other purposes. May also add a humidity sensor.
* **P3** - UEXT general purpose expansion header. Has 12C, SPI and UART. Can also be used as additional analog inputs e.g. for connecting methane sensor.

Solder the headers onto the board as shown in the images below.





4) External 5V power  
-------------------------------------

Optional source of higher current power input which can be used as an alternative to powering from the USB connector on the Teensy (500 mA limit). The slide switch (S2) can be used as an on/off switch for the device when using the external 5V power. 

Solder the blue 2-position terminal block onto the board as shown below. Make sure the terminal block is positioned with the connector side facing out.
 


Solder the switch onto the board as shown below.



5) Configuration and expansion headers
----------------------------------------------

These pins provide access to additional features on the Teensy and some additional configuration options for the device.

* AOUT (P8) - This header provides access to the onboard DAC (digital to analog converter) on the Teensy.  
* 3V3SEL (P4) - Selects between the 3.3V regulator on the Teensy or the higher current external 3.3V Pololu regulator. You might use the higher current Pololu regulator when using the XBEE or WiFly.
* PROG (P7) - Provides access to the Teensy program signal which reboots the microcontroller into Bootloader mode. (Development option).
* VBUS (P5) - For connecting the external power to the Teensy. If you are using the external power you will want to put a jumper on the pins.
* UEXT VOUT (P11) - Selects the power for the UEXT expansion header, whether it is 5V or 3.3V. For example, to select 5V, place a jumper on the right pins.

Solder the 2x2 pins into positions P4 and P11.



Take the 36-position male breakaway header and break off 3 sets of 2-position headers. Solder these into positions P5, P7 and P8. Solder with the longer pin facing up.



6) OpenLOG and 3V3 Headers
-------------------------------------

Take the same breakaway header from the previous step and break off a 6-position and a 4-position header. Solder these into positions U4 and U5 as shown in the image below. Solder with the shorter pin side facing up.

|

These pin headers will be used to connect the OpenLog SD card data logger and Pololu 3V3 optional power regulator later in the instructions. 



7) Teensy Headers
-------------------------------------

There are 3 of the 36-position (pos) female breakaway headers. These breakaway headers can be cut into customs lengths using a pair of wire clippers.  

* Take one of the breakaway headers and cut off two 14-position headers. 
* Take a second breakaway header and cut off two 5-position headers and two 7-position headers. 
* Place the custom headers into the board at position U6 as shown in the image below. You may find that you will need to sand the rough edges of the headers where they were cut to get the headers to all fit into the board. 

|

These female headers will be used to connect the Teensy later in the instructions. 



8) GPS, LCD and XBEE Headers
-------------------------------------

Use the remainder of the 36-position (pos) female breakaway header to break off the following headers: 

* 8 pos header x 1
* 9 pos header x 1

Solder these into positions U1 (9 pos header) and U3 (8 pos header). 
These female headers will be used to connect the Adafruit Ultimate GPS Breakout and Adafruit Monochrome 1.3" or 0.96" 128x64 OLED graphic display later in the instructions. 



Take the two pre-cut 10-position headers. These shorter headers are ready to use. Solder these into the board at position U2. 

These female headers will be used to connect the XBEE RF module or Sparkfun RN-XV WiFly later in the instructions. 



9) Placing large components
-------------------------------------

OpenLog SD card data logger
^^^^^^^^^^^^^^^^^^^^^^^^^^^^^^^^^^^^^^^^^^^^^^^^^^^^^^^^^^^^^^^^^^^^^^^^^^^^^^^^

Place the OpenLog onto the 6-pin header and solder in place as shown in the image below.



Pololu 3V3  power regulator
^^^^^^^^^^^^^^^^^^^^^^^^^^^^^^^^^^^^^^^^^^^^^^^^^^^^^^^^^^^^^^^^^^^^^^^^^^^^^^^^

Place the Pololu 3V3 module onto the 4-pin header and solder in place as shown in the image below.



XBEE/WiFly wireless communication module
^^^^^^^^^^^^^^^^^^^^^^^^^^^^^^^^^^^^^^^^^^^^^^^^^^^^^^^^^^^^^^^^^^^^^^^^^^^^^^^^

Insert the XBEE RF module or Sparkfun RN-XV WiFly into the sockets as shown in the image below. 
   


Adafruit Ultimate GPS Breakout
^^^^^^^^^^^^^^^^^^^^^^^^^^^^^^^^^^^^^^^^^^^^^^^^^^^^^^^^^^^^^^^^^^^^^^^^^^^^^^^^

Adafruit GPS Breakout board comes with a 9-pin array. Solder this onto the breakout board as shown in the images below.
   


Insert the GPS board into the 9-position female header as shown in the image below.



Adafruit OLED graphic display
^^^^^^^^^^^^^^^^^^^^^^^^^^^^^^^^^^^^^^^^^^^^^^^^^^^^^^^^^^^^^^^^^^^^^^^^^^^^^^^^

The Adafruit graphic display comes with an 8-pin array. Solder this onto the board as shown in the image below and insert the LCD display into the 8-position female header.



10) Teensy board
-------------------------------------

Take the Teensy header and solder onto the Teensy board as shown in the image below.



Program the Teensy with the Safecast Air firmware

|
   
Place the Teensy board into the female headers as shown below.



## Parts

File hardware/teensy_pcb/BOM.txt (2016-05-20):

QTY   Position          Description                                    Vendor                  Part #                     Notes
=================================================================================================================================================================
1      --               PCB, smaller than 10x15 cm size                 iTeadStudio
2      P1, P2           Mini hrouded header, 5x2                        Digikey                 WM18560-ND
1      P3,P11           Shrouded header, 5x2                            Digikey                 S9169-ND
1      P4               2x2 pin array                                   Digikey                 609-3225-ND
4      P5,P7,P8,P10     Breakaway header, male pins, 36 pos             Digikey                 3M9457-ND
1      P6               Screw terminal block, 2-pos                     Digikey                 ED2635-ND
1      P9               6-pin JST XH connector                          Digikey                 455-2271-ND
1      S1               Switch, 4-direction with center push            Online components       SKQUCAA010
1      S2               Slide switch                                    Digikey                 401-2000-ND
1      U1               Adafruit Ultimate GPS Breakout                  Adafruit                746
1      U2               XBEE                                            Sparkfun                WRL-08742
2      U2               10pin XBee Socket                               Sparkfun                PRT-08272
1      U3               Monochrome 1.3" 128x64 OLED graphic display     Adafruit                938
1      U4               OpenLog                                         Sparkfun                DEV-09530
1      U5               3.3V, 600mA step down voltage regulator         Pololu                  2106
1      U6               Teensy 3.1                                      Sparkfun                DEV-12646
1      U6               Teensy header                                   Digikey                 WM17453-ND
3      U1,3,6           Breakaway header, female, 36 pos                Digikey                 929974E-01-36-ND
1      U7               Resistor array, isolated                        Digikey                 4608X-2-102LF-ND
1      U8               Schmitt buffer                                  Digikey                 TC7SZ17FU(T5LJFTCT-ND
2      R29,R30          4.7k resistor (select via I2C requirements)     Digikey                 311-4.70KCRCT-ND    

Added/Changed
==================================================================================================================================================================
1      U9               Adafruit temperature humidity breakout          Adafruit/Digikey        2857/1528-1540-ND 
1      R27              20k resistor      (SM0805)                      Digikey                 311-20.0KCRCT-ND  
1      R28              12k resistor      (SM0805)                      Digikey                 311-12KARCT-ND  
1      R25              22 Ohm resistor   (SM0805)                      Digikey                 RMCF0805JT22R0CT-ND 
1      R26              10K resistor      (SM0805)                      Digikey                 311-10KARCT-ND 
1      C1               0.1uf ceram. cap. (SMO805)                      Digikey                 311-1361-1-ND  
1      Q1               P-Channel MOSFET  (SOT-323)                     Digikey                 DMP2160UWDICT-ND  
12     R1-23 (odd)      68k resistor (0.1%)                             Digikey                 YAG1958CT-ND 
12     R2-24 (even)     20k resistor (0.1%)                             Digikey                 P20KDACT-ND  

Removed
===================================================================================================================================================================

1      P10              5-pin JST XH connector                          Digikey                 455-2270-ND         
2      R25,R26          10k resistor                                    Digikey                 S10KQCT-ND

1      R27              20k resistor (or 47k, 100k)                     Digikey                 S20KQCT-ND, S47KQCT-ND, CF18JT100KCT-ND
1      R28              12k resistor                                    Digikey                 S12KQCT-ND
1      C1               0.1uf ceramic capacitor 0.1" lead spacing       Digikey                 399-4151-ND
12     R1-23 (odd)      68k resistor (1%)                               Digikey                 S68KCACT-ND
12     R2-24 (even)     20k resistor (1%)                               Digikey                 S20KCACT-ND

Hardware
==================

6       7/16” long standoffs       McMaster       91780A511
2       Ribbon cable connector     Digikey        WM14310-ND
1       Ribbon cable               Digikey        MC10L-5-ND

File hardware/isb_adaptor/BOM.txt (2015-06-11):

QTY   Position          Description                                    Vendor                  Part #                     Notes
=================================================================================================================================================================
1      P1             Mini shrouded header, 5x2                          Digikey                 WM18560-ND
3      C1,C3,C5       10nF  ceramic capacitor 0.1" lead spacing          Digikey                 399-9858-1-ND
4      C2,C4,C6, C7   0.1uF ceramic capacitor 0.1" lead spacing          Digikey                 399-4151-ND
3      P2,P3,P4       6x1 female header (receptacle)                     Digikey                 S7004-ND
1      U1             TMP36 temperature sensor                           Digikey                 TMP36GT9Z-ND

Hardware
==================
2       Ribbon cable connector     Digikey        WM14310-ND
1       Ribbon cable               Digikey        MC10L-5-ND

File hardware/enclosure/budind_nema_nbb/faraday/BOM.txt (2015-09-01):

Materials
----------

1) 24"x 48"x 0.25" extruded ABS sheet (Interstate plastics). Note, you can
get multiple faraday cages from each sheet. 

2) Aluminum Male-Female Threaded Hex Standoff, 1/4" Hex, 5/8" Length, 4-40
Screw Size.  McMaster Carr 93505A820.

3) Copper Woven Wire Cloth, 22 x 22 Mesh, .012" Wire Diameter, 24" x 24"
Sheet.  McMaster Carr 9224T59. 

Tools 
-----
1) Hammer-Driven Small Hole Punch size 9/64", 11/64", 13/64".  McMaster Carr
3424A13, 3424A15, 3424A17. Used for puching holes in mesh.

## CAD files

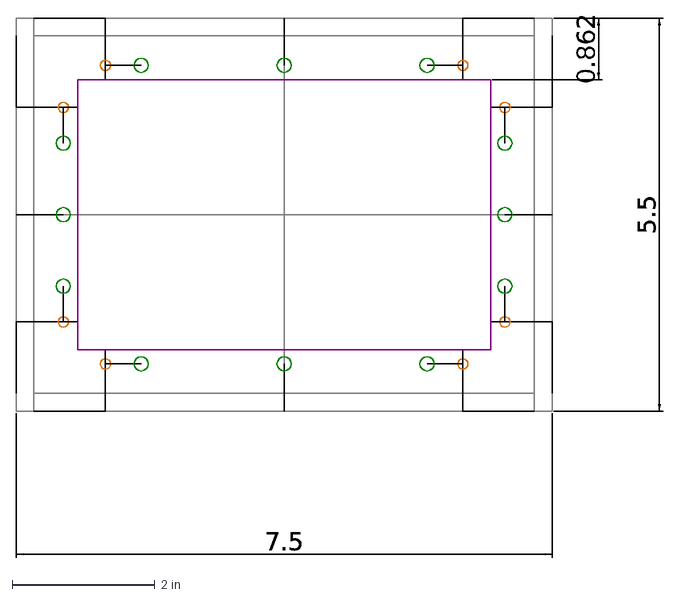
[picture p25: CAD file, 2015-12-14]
hardware/enclosure/budind_nema_nbb/faraday/faraday_top.dxf
5.5
7.5
0.862

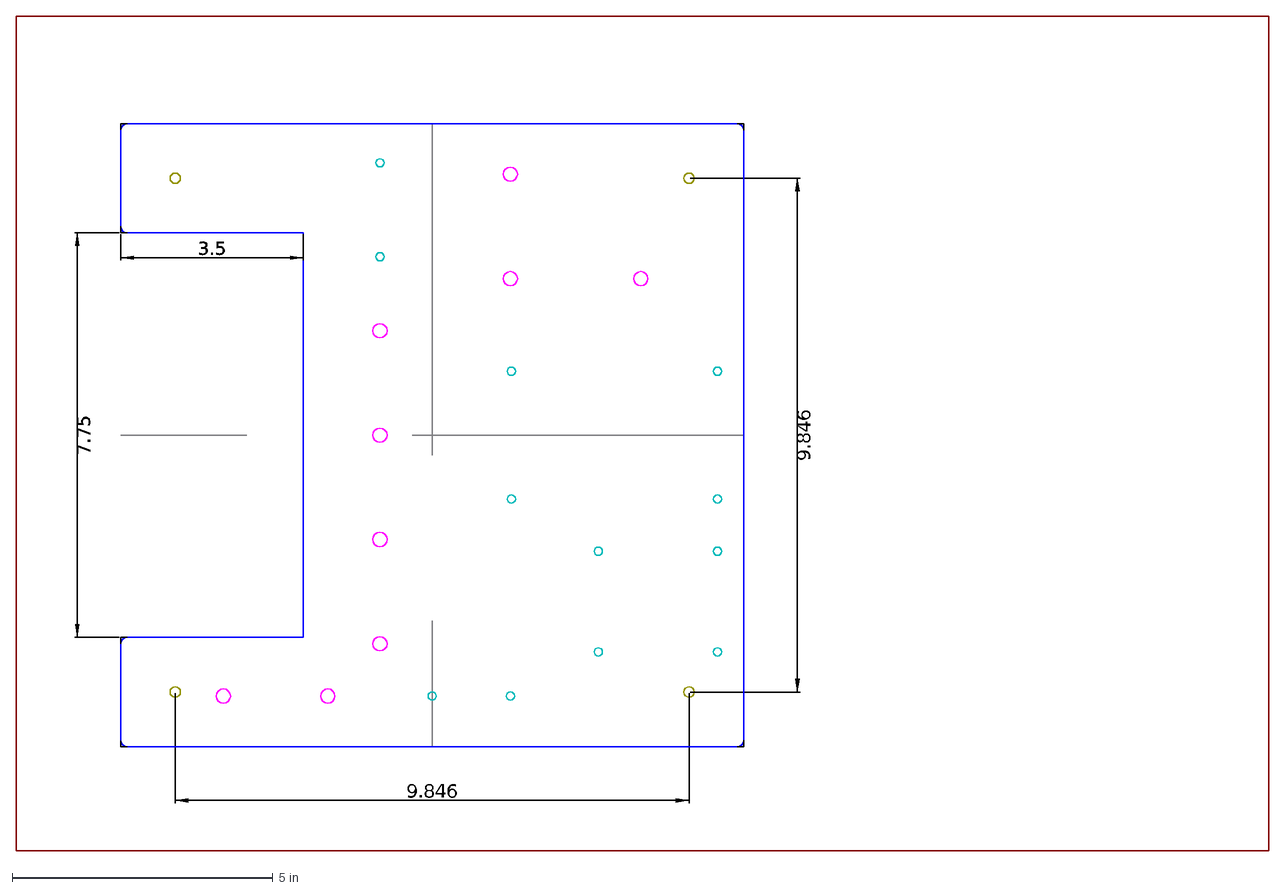
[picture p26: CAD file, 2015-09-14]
hardware/enclosure/budind_nema_nbb/layouts/cnc/floor_layout/floor_layout.dxf
9.846
7.75
3.5

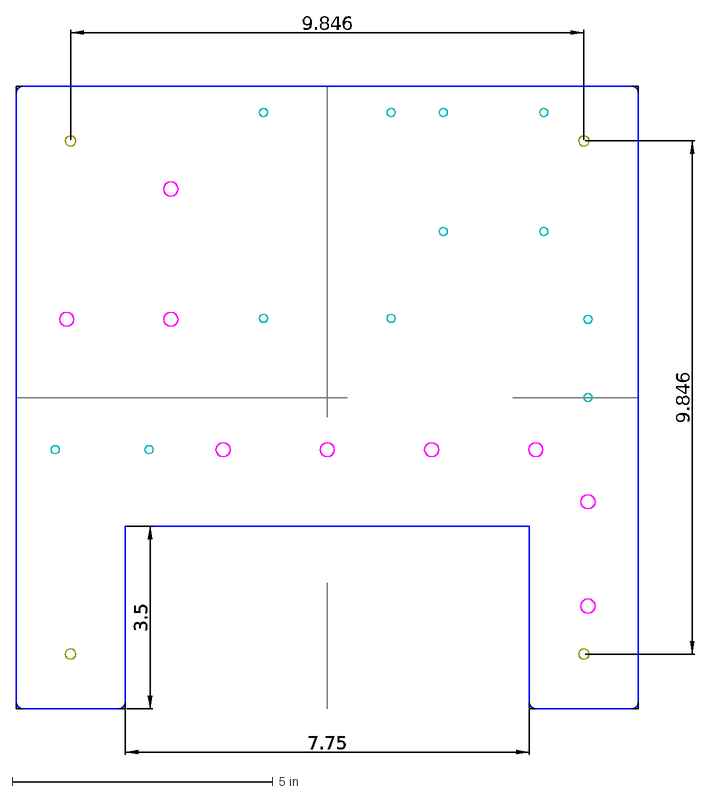
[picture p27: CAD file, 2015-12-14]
hardware/enclosure/budind_nema_nbb/layouts/floor_layout.dxf
9.846
7.75
3.5

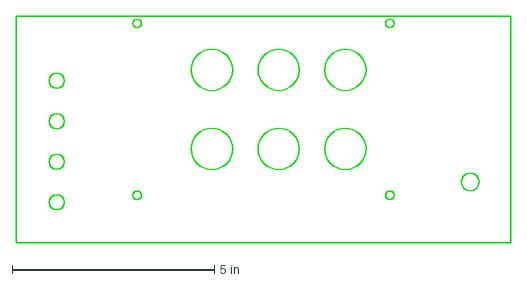
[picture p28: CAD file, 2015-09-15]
hardware/enclosure/budind_nema_nbb/layouts/lasercutting/bottom_layout/hole_template.dxf
12.2 x 5.59 in

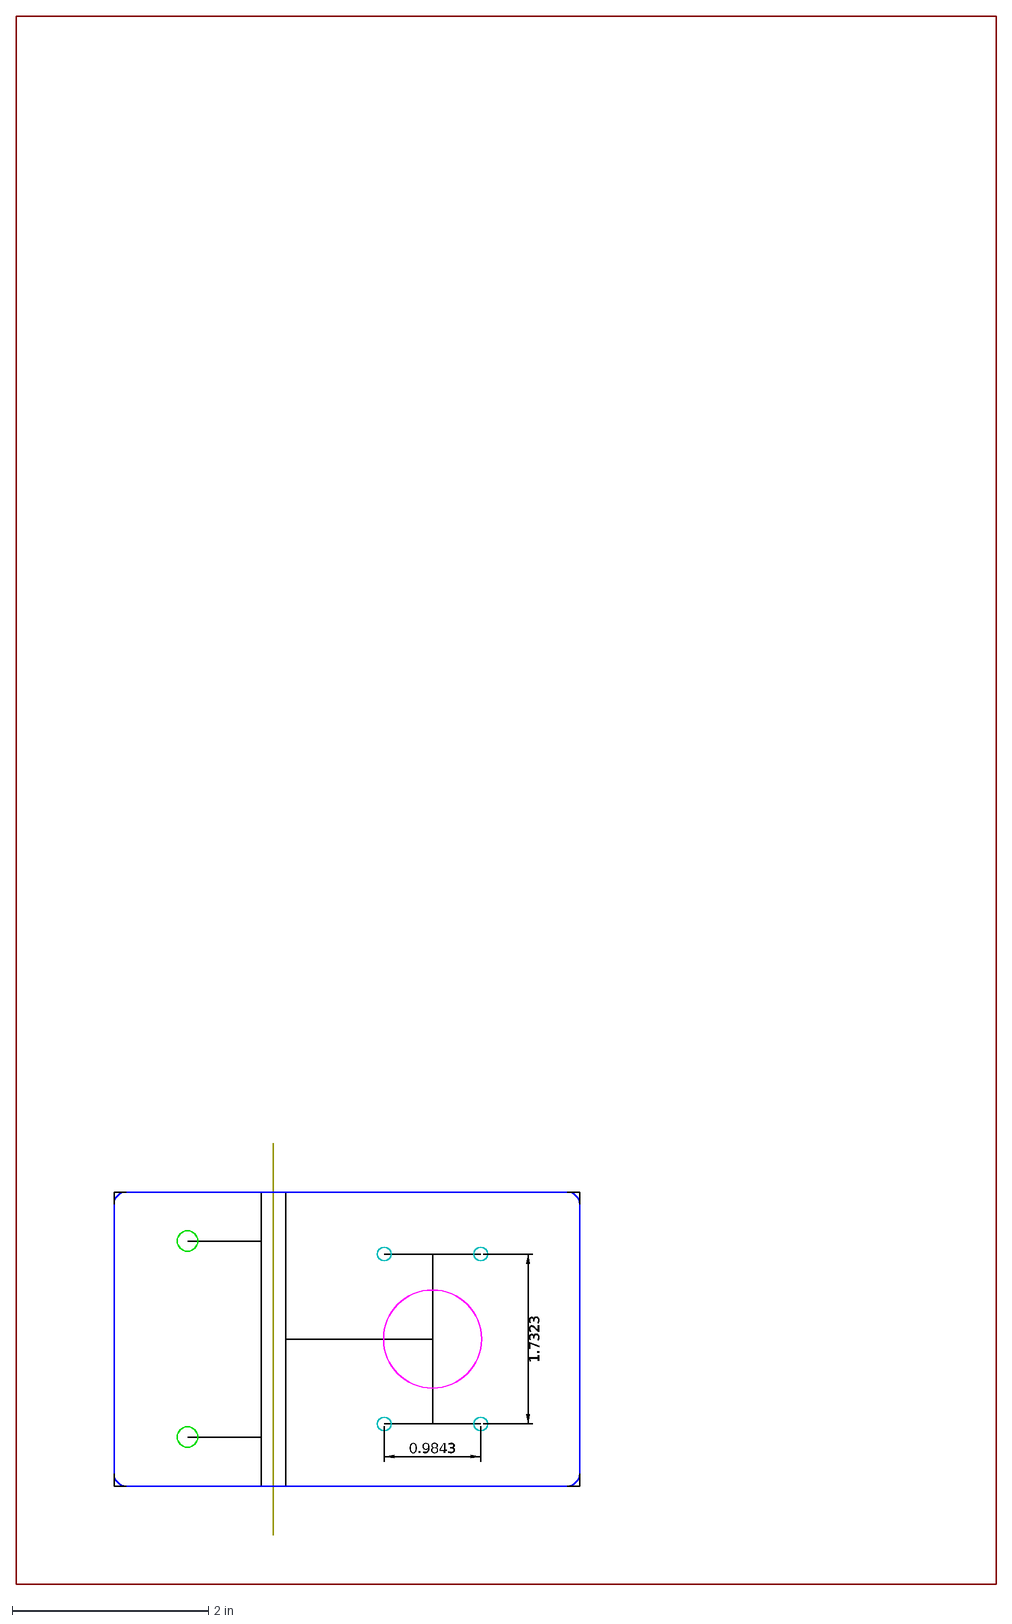
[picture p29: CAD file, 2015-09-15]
hardware/enclosure/budind_nema_nbb/pm_bracket/cnc/pm_bracket.dxf
1.7323
0.9843

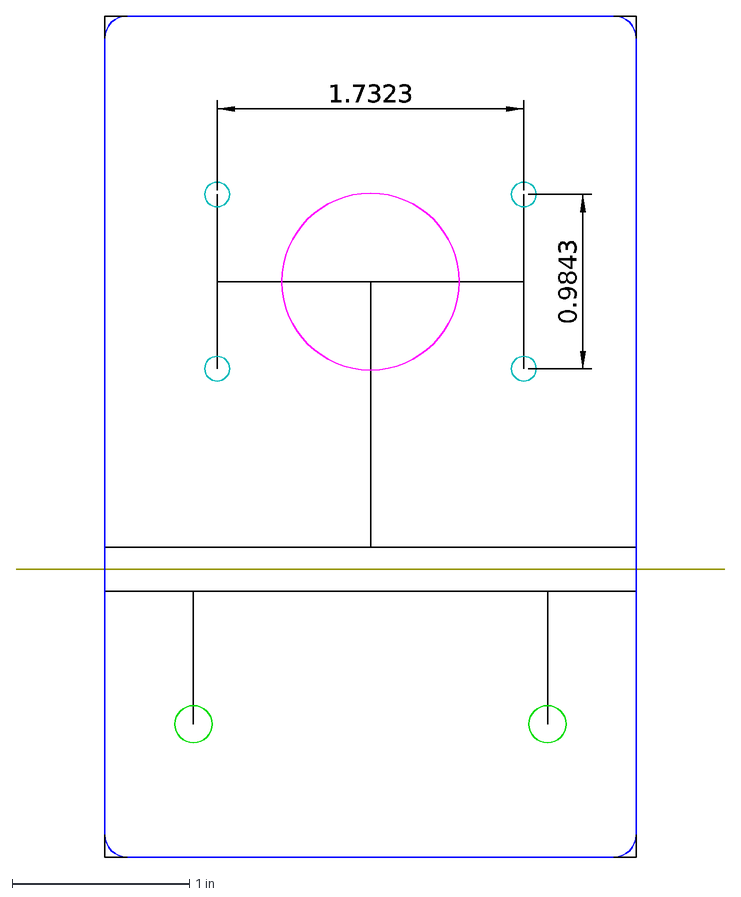
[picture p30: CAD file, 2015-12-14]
hardware/enclosure/budind_nema_nbb/pm_bracket/pm_bracket.dxf
1.7323
0.9843

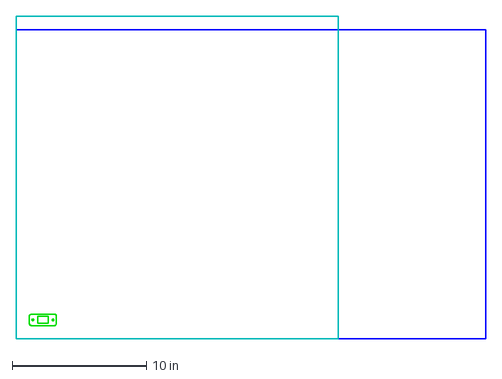
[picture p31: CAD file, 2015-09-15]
hardware/enclosure/budind_nema_nbb/power_switch_holder/lasercutting/power_switch_holder.dxf
35.0 x 24.0 in

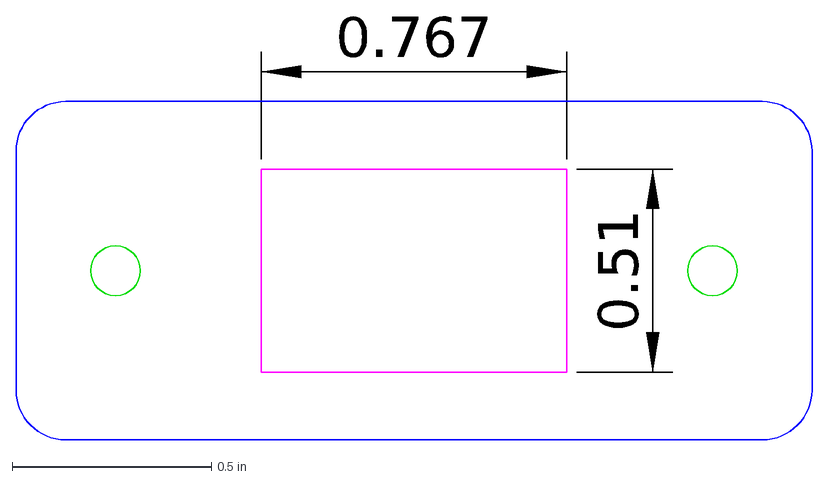
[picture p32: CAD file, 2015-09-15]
hardware/enclosure/budind_nema_nbb/power_switch_holder/power_switch_holder.dxf
0.767
0.51

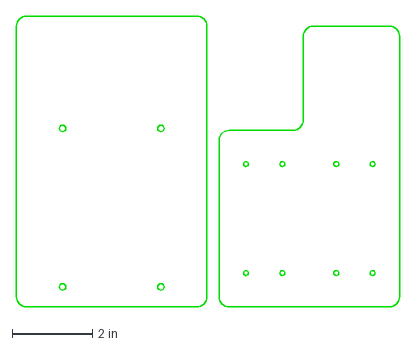
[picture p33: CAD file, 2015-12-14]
hardware/enclosure/pelican_1120/lasercutting/floor_plates/floor_plates.dxf
9.55 x 7.25 in

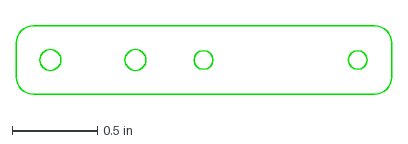
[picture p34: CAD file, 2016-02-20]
hardware/enclosure/pelican_1120/lasercutting/methane_sensor_mount/methane_sensor_mount.dxf
2.21 x 0.4 in

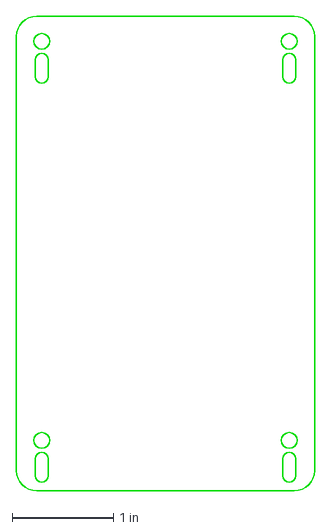
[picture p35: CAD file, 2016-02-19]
hardware/enclosure/pelican_1120/lasercutting/pcb_adjust_plate/pcb_adjust_plate.dxf
2.95 x 4.70 in

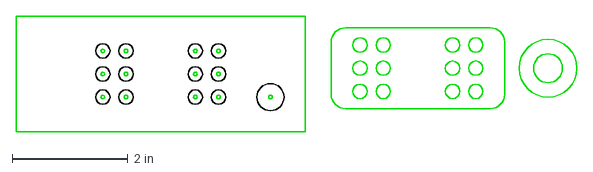
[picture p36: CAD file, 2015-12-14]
hardware/enclosure/pelican_1120/lasercutting/screen_plates/screen_plates.dxf
9.70 x 2.00 in

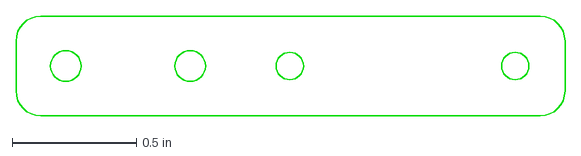
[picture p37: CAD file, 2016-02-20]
hardware/enclosure/pelican_1120/methane_sensor_mount.dxf
2.21 x 0.4 in

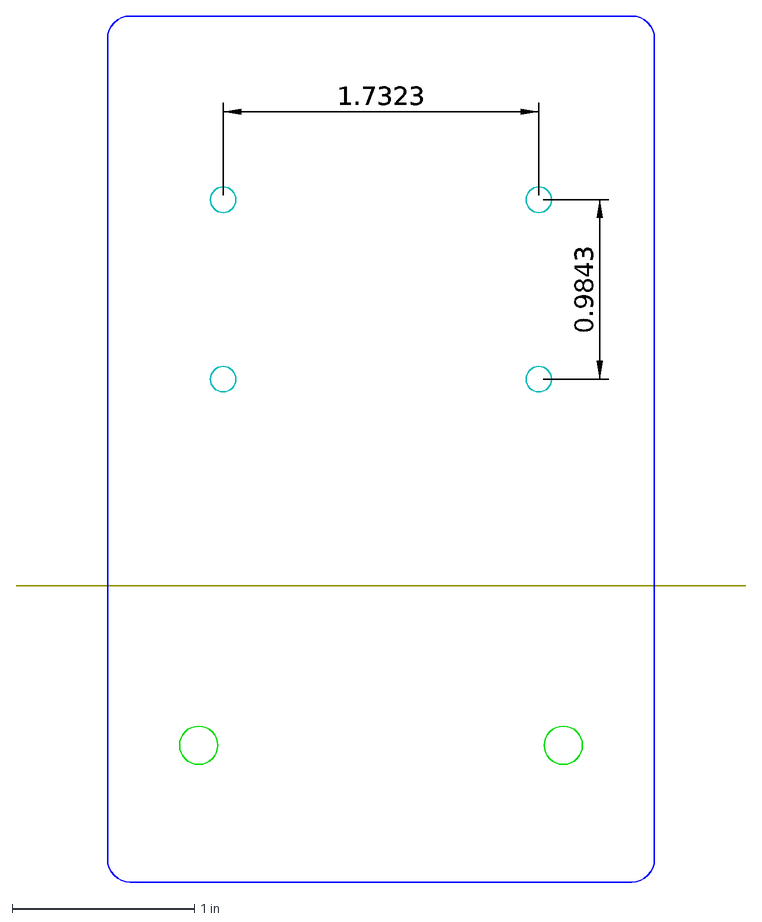
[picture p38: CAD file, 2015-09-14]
hardware/enclosure/pm_bracket/pm_bracket.dxf
1.7323
0.9843

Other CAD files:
hardware/enclosure/budind_nema_nbb/faraday/cnc/abs_0p25in/layout.dxf
hardware/enclosure/layouts/floor_layout.dxf
hardware/enclosure/seahorse_120/methane_only/lower_insert/lower_insert.dxf
hardware/enclosure/seahorse_120/methane_only/upper_insert/upper_insert.dxf
hardware/enclosure/budind_nema_nbb/faraday/faraday_floor.dxf
hardware/enclosure/budind_nema_nbb/faraday/faraday_mesh_lower.dxf
hardware/enclosure/budind_nema_nbb/faraday/faraday_mesh_upper.dxf
hardware/enclosure/budind_nema_nbb/faraday/faraday_side_1.dxf
hardware/enclosure/budind_nema_nbb/faraday/faraday_side_2.dxf
hardware/enclosure/budind_nema_nbb/faraday/faraday_side_3.dxf
hardware/enclosure/budind_nema_nbb/faraday/isb_footprint.dxf
hardware/enclosure/budind_nema_nbb/layouts/bottom_layout.dxf
hardware/enclosure/budind_nema_nbb/layouts/lasercutting/bottom_layout/combined_template.dxf
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

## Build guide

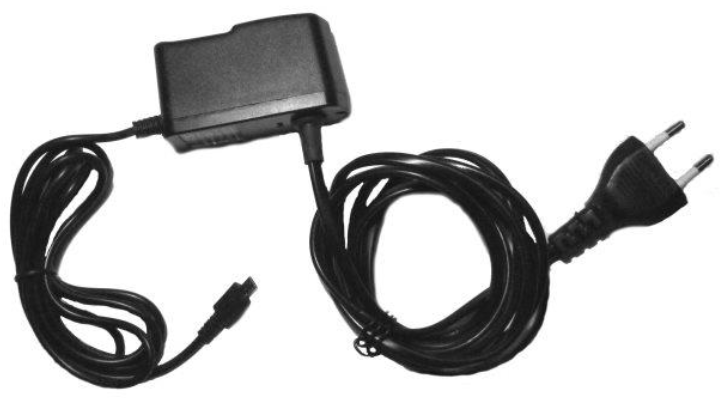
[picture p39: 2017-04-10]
images/electronics-assembly/finished-wall-adapter-with-Europlug.png

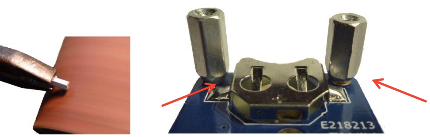
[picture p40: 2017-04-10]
images/electronics-assembly/Trimming-the-GPS-Standoffs.png

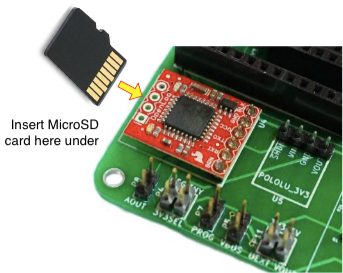
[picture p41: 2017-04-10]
images/electronics-assembly/openlog-unit-soldered.png

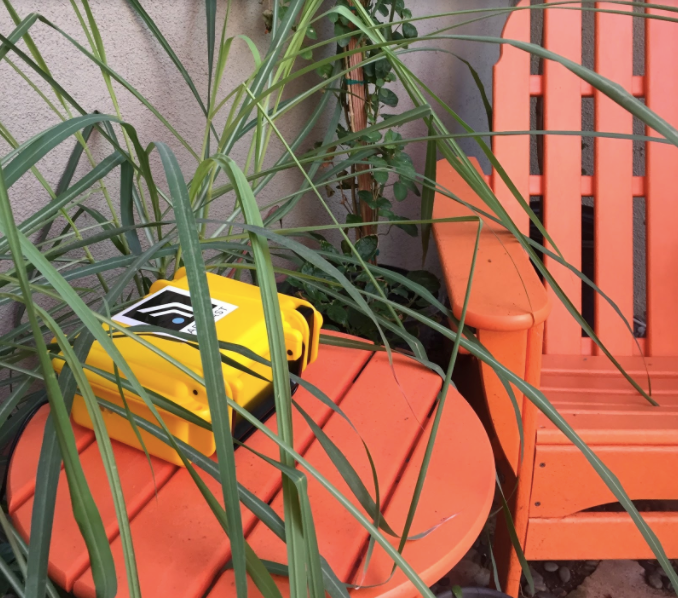
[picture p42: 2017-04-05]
images/hardware-instructions/25.png

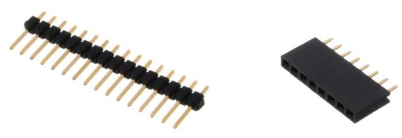
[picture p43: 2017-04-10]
images/electronics-assembly/pin-headers.png

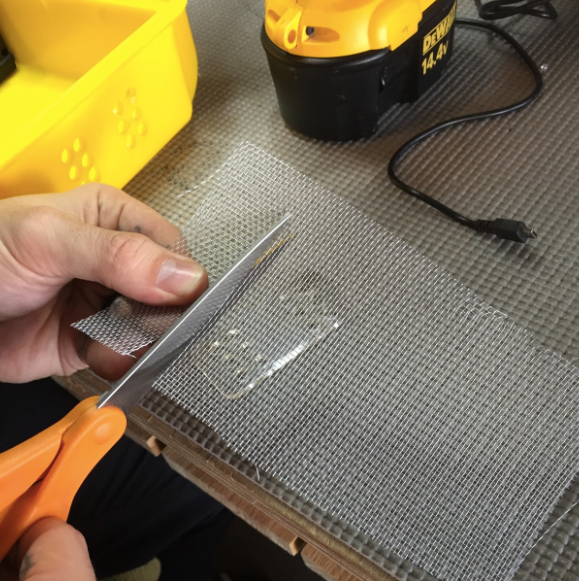
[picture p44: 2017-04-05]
images/hardware-instructions/12.png

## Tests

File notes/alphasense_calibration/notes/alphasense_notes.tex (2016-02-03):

\documentclass[letterpaper]{article}
\usepackage{graphicx}
\usepackage{fullpage}
\usepackage{setspace}
\usepackage[parfill]{parskip}
\vfuzz2pt
\hfuzz2pt
\onehalfspacing

\newcommand{\cgas}{C_{\mathrm{gas}}}
\newcommand{\cgasnorm}{C_{\mathrm{gas,*}}}
\newcommand{\wrk}{w}
\newcommand{\aux}{a}
\newcommand{\wrknorm}{\wrk_{\mathrm{*}}}
\newcommand{\auxnorm}{\aux_{\mathrm{*}}}

\begin{document}

\title{Safecast-Air Notes: Alphasense 4-Electrode Sensors}

\date{}
\maketitle

\section{Calculating gas concentration from the electrode voltages}

In this section I discuss how to calculate the gas concentration, $\cgas$, (in
ppb) from the voltage measured at the working electrode, $\wrk$, and the
voltage measured at the auxiliary electrode, $\aux$.   

I examine the following points:

\begin{itemize}

    \item The form of the factory calibration for the Alphasense 4-electrode
        gas sensors as given in the user manuals for the ISB and 3-way AFE
        signal conditioning boards. 

    \item Under what conditions might we calculate $\cgas \leq 0$? Both Rob and
        I have observed this with current Safecast-Air prototypes and we would like
        to understand why it happens and how to fix it.

    \item Possible methods for re-zeroing a sensor.  

\end{itemize}

For the purposes of these notes I am assuming the working and auxiliary
voltages are being read from a sensor operating off a 5V supply using either
the ISB or 3-way AFE signal conditioning boards. I am also assuming that
the voltages have not been scaled via voltage dividers. Note, the current
Safecast-Air prototype uses a voltage divider to scale the electrode voltages
from the 0-5V range to a 0-1.2V range in order to be sampled by an analog input
on the teensy 3.x using the internal 1.2V reference source. I will consider this
scaling in a later section.  However, for the purposes of this section we will
assume that the measured voltages are in the original 0-5V range. 

Also, note that computing the gas concentration for the $\mathrm{O_3}$ sensor
is special case which requires a paired $\mathrm{NO_2}$ sensor in order to
perform a subtraction. This will also be discussed in a later section.

\subsection{Factory calibration}
The factory calibration, which is used to convert the voltages to gas
concentration,  consists of three constants:
\begin{itemize}
    \item $\wrk_0$ $=$  working electrode total zero (V),
    \item $\aux_0$ $=$  auxiliary electrode total zero (V),
    \item $S$ $=$  the sensor's sensitivity (V/ppb).
\end{itemize}

In the Alphasense documentation (See ISB and 3-way AFE user manuals) the procedure for calculating
$\cgas$ from electrode voltages is given as follows: 

\begin{enumerate}
    \item Zero the working electrode voltage $(\wrk - \wrk_0)$, 
    \item Zero the auxiliary electrode voltage $(\aux - \aux_0)$, 
    \item Correct drift by subtracting the zeroed auxiliary elctrode voltage from the zeroed
        working electrode voltage $(\wrk - \wrk_0) - (\aux - \aux_0)$,  
    
    \item Calculate the gas concentration, $\cgas$,  (in ppb) by dividing by the
        drift corrected voltage by the sensor sensitivity, S. This results in
        the folliwng equation for gas concentration: 

\end{enumerate}

\begin{equation} \label{factorycal}
    %\cgas = (1/S)\left[(\wrk - \wrk_0) - (\aux - \aux_0)\right].
    \cgas = \frac{(\wrk - \wrk_0) - (\aux - \aux_0)}{S}
\end{equation}

\subsection{Linear relationship between $\cgas$ and $\wrk-\aux$}
It is easy to see that equation \ref{factorycal} is really just a simple
linear relationship between the difference in the electrode voltages,
$(\wrk-\aux)$, and the gas concentration, $\cgas$.  As such we can rearrange
this equation into the following form
\begin{equation} \label{linearcal}
    \cgas= \alpha (\wrk - \aux) + \beta
\end{equation}
where the slope, $\alpha$, and offset, $\beta$, are constants given by
\begin{equation}
    \alpha = \frac{1}{S}
\end{equation}
and
\begin{equation}
    \beta = \frac{\aux_0 - \wrk_0}{S}.
\end{equation}

Knowing that we should expect a linear relationship between $\cgas$ and
$(\wrk-\aux)$ should be useful when performing an empirical calibration/test of
the sensor. During such a calibration/test we would most likely measure the
working and auxiliary electrode voltages over a range of different gas
concentrations. After performing such measurements one of the first things we
would probably want to look at is a plot of $\cgas$  vs $(\wrk-\aux)$.  From
the form of the factory calibration we would expect to see a linear
relationship in the plot.  In addition we should be able to perform a  linear
regression on this data in
order to determine empirical values for the calibration coefficients $\alpha$
and $\beta$. 

Notes:
\begin{itemize}

    \item The slope of the linear relationship is given by $1/S $ and thus
        depends only on the sensor's sensitivity.   

    \item The $y$-intercept of the linear relationship, the value of $(\wrk -
        \aux)$ for which we get $\cgas = 0$, is given by $(\wrk_0 - \aux_0)$
        and  depends only on the electrode zeros.  
\end{itemize}

Since the $y$-intercept is only related to the electrode zeros it may be
possible to re-zero the sensor/calibration without using expensive test
equipment - either using clean test gas or knowing the current atmospheric gas
concentration. I will elaborate further on this idea later in this section.

\subsection{Under what conditions would we calculate $\cgas \leq 0$?} 

As Rob and I have both seen negative gas concentrations, $\cgas \leq 0$,
reported by the early Safecast-Air prototypes it is interesting to consider
under what conditions this might happen.  From the $y$-intercept calculated in
the previous section we can see that the $\cgas \leq 0$ whenever

\begin{equation}  \label{zerocond2}
    \wrk-\aux \leq \wrk_0 - \aux_0.
\end{equation}
This can be as read as saying that $\cgas \leq 0$ whenever the difference
between the working and auxiliary voltages is less then the difference between
the working and auxiliary total zeros (in the calibration).  In any case it
is clear that  the values of electronic zeros, $\wrk_0$ and $\aux_0$,  are what
determine at what point this zero crossing occurs. Thus a device which is frequently
reporting negative gas concentration probably has an incorrectly set zero(s). 

Some thoughts:

\begin{enumerate}

    \item I'm not completely sure under what conditions we would expect to see
        this. However, the factory calibration is performed under a certain set
        of conditions, i.e., temperature, humidity, etc.  It is very possible
        that the electronic zeros do depend on external factors to some extent.
        In which case we can expect to see some zeroing issues when the sensor
        is operated outside of the calibration conditions.  It is also possible
        that the working and auxiliary electrode zeros may change over time and
        that the sensors need to be re-zeroed occasionally.

    \item Assuming the linear relationship is valid - what are the consequences
        of an incorrectly set zero?  Because the electrode zeros only effect
        the $y$-intercept and not the slope of the linear relationship an
        incorrectly set zero will result in a constant offset in the calculated
        gas concentration.  If this constant offset is in a negative direction
        then, at sufficiently low (actual) gas concentrations, this will result
        in the sensor erroneously reporting a negative gas concentration.

    \item Since gas concentrations which are less than zero don't make physical
        sense it might be reasonable to consider clamping the $\cgas$ values in
        software so that they are always $\geq 0$. Here I am assuming
        that the cause of the negative gas concentration is due to a problem
        with sensor zero - perhaps due to a change in temperature etc. - and
        not due to some other error.  Since we also report the raw 
        working and auxiliary electrode voltages in the JSON data this won't
        result in unrecoverable data loss. 

\end{enumerate}

\subsection{Re-zeroing the sensor}

Prior to re-zeroing the user manual suggests running the sensor for
at least 6 hours in clean air in order to stabilize.

\subsubsection{Using zero air}
If we have zero air (synthetic or scrubbed/cleaned zero air) available then
re-zeroing the sensor is straight forward and we can follow the procedure
described in the user manual.  

\begin{enumerate}
    \item Apply zero air to the sensor for 20min.  
    \item Record the voltages at both the working and auxiliary electrodes. 
\end{enumerate}

The recorded values are then the new working and auxiliary electrode zeros,
$\wrk_0$ and $\aux_0$.  It looks like ``zero'' air can be purchased in small
bottles for a fairly reasonable price. In order to perform the procedure we
would probably need some sort of gas chamber ... maybe make one?

\subsubsection{Quick and dirty - using a known gas concentration}
Another possibility, which is perhaps a bit more quick and dirty, but might be
used to correct a sensor which has an obvious issue with the sensor zero is as
follows.  Say we know the current  gas concentration $\cgasnorm$ maybe from a
reference sensor or perhaps we are in known ``clean'' air and we can use the
baseline atmospheric concentrations.  After the sensor stabilization period we
record the working and auxiliary electrode voltages  $\wrknorm$ and $\auxnorm$
which result from operating at this known  gas concentration. 
    
We then have 
\begin{equation}
    \cgasnorm = \frac{(\wrknorm - \auxnorm) - (\wrk_0 - \aux_0)}{S}
\end{equation}
We can solve this equation for the $y$-intercept, $(\wrk_0 - \aux_0)$, as follows:
\begin{equation}
    \wrk_0 - \aux_0 = \wrknorm - \auxnorm - S \cgas 
\end{equation}
Since the linear relationship in equation \ref{linearcal}  only depends
on difference $(\wrk_0 - \aux_0)$ and not on the individual values of $\wrk_0$
and $\aux_0$ we can set these values relatively arbitrarily (in our
calibration). As long as the difference is equal to $\wrknorm - \auxnorm - S \cgas$
we get the same linear relationship. Thus a set of ``working'' zeroes might be
defined
by 
\begin{equation}
    \wrk_0 = \frac{ \wrknorm - \auxnorm - S\cgas}{2}
\end{equation}
and 
\begin{equation}
    \aux_0 = - \frac{\wrknorm - \auxnorm - S \cgas}{2}.
\end{equation}

\end{document}

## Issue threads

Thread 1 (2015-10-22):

Split particulate sensor from gas sensors housing. Smaller size and allows for more flexible deployment when air flow needs to be thought of.

nokton, 2015-10-22:

seanbonner, 2015-10-22:
I believe this is the current plan - separating out mobile and static deployments. Mobile will be smaller and have no particulate and static will be larger allowing for it. That's part of the modular design spec from the beginning. @willdickson can confirm..

nokton, 2015-11-06:
What about entering the current plan in this list so we all know what's already in the works. @willdickson doable?

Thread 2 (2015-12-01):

Fix handling of NO2 and NO2/O3 sensors

willdickson, 2015-12-01:
For the NO2/O3 sensors in order to get just the O3 values you need to subtract NO2 current is from the O3/NO2 current and then multiply by the ppb conversion factor for O3.

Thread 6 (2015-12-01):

Add serial numbers for each channel of data.

willdickson, 2015-12-01:
Ensure going forward that the air device data comes with serial numbers for each channel of data it sends up (similar to how the bgeigies have serial numbers). right now the bgeigies do this by having that number (e.g., mine is 2313) on the SD card for the air devices each channel of each sensor will need a number on the SD card.

See comments by Mat Schaffer and Edouard Lafargue
https://safecast.slack.com/archives/safecast-air/p1444264973000016
https://safecast.slack.com/archives/safecast-air/p1444269372000024

willdickson, 2015-12-02:
Added.

Closed 2015-12-02.

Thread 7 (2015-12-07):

Buzzer for alarm errors

robouden, 2015-12-07:
Add buzzer for error or alarrms in case of startup failure of for alarm if preset values are exceeded.

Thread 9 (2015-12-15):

If sensors are disconnected error message on screen

robouden, 2015-12-15:
If disconnected sensor , default measurements are coming in , data should not be displayed instead an error massage would notify user that sensor is not connected.

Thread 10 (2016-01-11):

Enable output of JSON data packets on serial port

elafargue, 2016-01-11:
So that we can monitor a running Safecast Air unit real time using a XBee/BLEBee-compliant module. Currently, the Safecast air firmware only writes to the microSD but does not output to the serial port, it seems.

robouden, 2016-01-12:
Ed,

Can be easy enabled. I get serial out from the Teensy and that I can send
to the Xbee.

rob

Regards,
Rob Oudendijk Yuka Hayashi
http://yr-design.biz   http://oudendijk.biz  http://about.me/robouden
tel +81 80-22605966  Skype: robouden  Facebook:robouden
<http://on.fb.me/QeKw2P> twitter:robouden <http://bit.ly/RAiSTC>

On Tue, Jan 12, 2016 at 2:55 AM, Edouard Lafargue <notifications@github.com>
wrote:

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

elafargue, 2016-01-12:
I don't have a Teensy, so I can't test... can you do the change in the firmware? I'm working on the Android app side.

robouden, 2016-01-12:
Yes, can do. Later today.

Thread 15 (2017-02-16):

Bad OPC-N2 data; json encoding with opportunity for improvement

rayozzie, 2017-02-16:
Will, the first two below may in fact be the same issue.

In trying to process the JSON data coming out of the unit I noticed several things:

The first is that occasionally data values for PM are literally 0.00000000.  I have struggled and beaten my head against the wall trying to find the correct SPI timing for the OPC-N2, and this seems suspiciously like a timing issue.  Furthermore, I think you'd agree that (unlike the plantower, which returns integer values) the fact that the OPC-N2 represents PM values with floats means that more often than not the value may be extremely small but it is rarely exactly 0.

The second issue is that when it is that bizarre value (I mean, why wouldn't it just be formatted as 0 or 0.0?, it is also malformed JSON in that the value has a space character before the leading 0.  I initially noticed this because my JSON parser's number parsing actually stopped parsing the number when it hit that leading space character and threw an error.)

The third issue, which is likely not worth fixing but which I'll note here, is that it is really kind of difficult to use Safecast Air's JSON output with strongly-typed languages - in my case golang.  The problem is that you are being very loose with number vs text data types.  For example, you represent sensor_id as a good JSON number: it is a field name in quotes followed by a number that is not in quotes.  However, for (I believe) all of your other numeric values - device id, value, lat/lon/height, you are not encoding them as JSON numbers but rather as JSON text strings.  I'm past this and I wrote a custom unmarshaler to deal with the inconsistency, but I thought I'd note it in case you're interested.

Sample data follows that show all of the above happening in a very brief time:

2017-02-16 02:42:08 Received payload for 50001 from safecast-air:172.31.18.183
{"captured_at":"2017-2-16T2:42:6Z","longitude":"-118.26808268","latitude":"34.11895345","device_id":"50001","value":" 0.00000000","unit":"PM1","height":"1.16400","devicetype_id":"OPCN2","sensor_id":29}

2017-02-16 02:42:21 Received payload for 50001 from safecast-air:172.31.18.183
{"captured_at":"2017-2-16T2:42:6Z","longitude":"-118.26808268","latitude":"34.11895345","device_id":"50001","value":" 0.00000000","unit":"PM10","height":"1.16400","devicetype_id":"OPCN2","sensor_id":31}

2017-02-16 02:47:07 Received payload for 50001 from safecast-air:172.31.18.183
{"captured_at":"2017-2-16T2:47:5Z","longitude":"-118.26803385","latitude":"34.11893311","device_id":"50001","value":"1.02629","unit":"PM1","height":"1.22600","devicetype_id":"OPCN2","sensor_id":29}

2017-02-16 02:47:17 Received payload for 50001 from safecast-air:172.31.18.183
{"captured_at":"2017-2-16T2:47:5Z","longitude":"-118.26803385","latitude":"34.11893311","device_id":"50001","value":"1.44535","unit":"PM10","height":"1.22600","devicetype_id":"OPCN2","sensor_id":31}

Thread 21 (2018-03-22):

Unable to see my data?

DT304, 2018-03-22:
My data stopped showing up in June 10, 2017?  I don't know if this is a problem on my end, is my SAFECAST,.TXT file a problem?  Can anyone else see my device?  Is the API I am using correct?  I have tried to check the gateways, should they be:  "gw01.safecast.org",gq02.safecast.org" or "107.161.164.166","107.161.164.163"?

I would really like to solve this.  Other wise my monitor is a very expensive tree ornament.

https://goo.gl/88QCht shows my data.  But the quarry:

http://dev.safecast.org/en-US/measurements.json?device_id=50006.  only shows data from June 10, 2017?

Also https://goo.gl/88QCht shows only 3 of the 11 monitors on line?  I have to turn mine off then back on periodically to get it to keep reporting data?

Is this program dead?

Regards, JOHN

robouden, 2018-03-23:
I checked the logs on the gateway and your data is coming in. .. a log file named 20180322_50006.txt with todays data:

{"captured_at":"2018-03-22T15:50:29Z","longitude":null,"latitude":null,"device_id":"50006","value":"38.26354","unit":"PM2.5","height":"21.55100","devicetype_id":"OPCN2","sensor_id":30}
{"errors":{"location":["can't be blank"]}}
--------------------------------------------------------------------------------
{"captured_at":"2018-03-22T15:50:31Z","longitude":null,"latitude":null,"device_id":"50006","value":"38.27124","unit":"PM10","height":"21.55100","devicetype_id":"OPCN2","sensor_id":31}
{"errors":{"location":["can't be blank"]}}
--------------------------------------------------------------------------------
{"captured_at":"2018-03-22T15:55:35Z","longitude":null,"latitude":null,"device_id":"50006","value":"23.34974","unit":"TEMPC","height":"21.52900","devicetype_id":"SHT31","sensor_id":90}
{"errors":{"location":["can't be blank"]}}
--------------------------------------------------------------------------------
{"captured_at":"2018-03-22T16:00:40Z","longitude":null,"latitude":null,"device_id":"50006","value":"17.85613","unit":"PM10","height":"21.51800","devicetype_id":"OPCN2","sensor_id":31}
{"errors":{"location":["can't be blank"]}}
--------------------------------------------------------------------------------
{"captured_at":"2018-03-22T16:00:42Z","longitude":null,"latitude":null,"device_id":"50006","value":"23.56069","unit":"TEMPC","height":"21.51800","devicetype_id":"SHT31","sensor_id":90}
{"errors":{"location":["can't be blank"]}}
--------------------------------------------------------------------------------
{"captured_at":"2018-03-22T16:00:43Z","longitude":null,"latitude":null,"device_id":"50006","value":"25.62295","unit":"HUMD%","height":"21.51800","devicetype_id":"SHT31","sensor_id":91}
{"errors":{"location":["can't be blank"]}}
--------------------------------------------------------------------------------
{"captured_at":"2018-03-22T16:09:12Z","longitude":null,"latitude":null,"device_id":"50006","value":"20.30469","unit":"PM1","height":"21.30100","devicetype_id":"OPCN2","sensor_id":29}
{"errors":{"location":["can't be blank"]}}
--------------------------------------------------------------------------------
{"captured_at":"2018-03-22T16:14:12Z","longitude":null,"latitude":null,"device_id":"50006","value":"20.80634","unit":"PM1","height":"21.32600","devicetype_id":"OPCN2","sensor_id":29}
{"errors":{"location":["can't be blank"]}}
--------------------------------------------------------------------------------
{"captured_at":"2018-03-22T16:19:20Z","longitude":null,"latitude":null,"device_id":"50006","value":"20.56267","unit":"PM1","height":"21.35400","devicetype_id":"OPCN2","sensor_id":29}
{"errors":{"location":["can't be blank"]}}
--------------------------------------------------------------------------------

robouden, 2018-03-23:
Data from other air sensors like 50011 is coming in correctly..

robouden, 2018-03-23:
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

DT304, 2018-03-29:
My unit is 50006?  Not 50011

-----Original Message-----
From: Rob Oudendijk <notifications@github.com>
To: Safecast/Safecast-Air <Safecast-Air@noreply.github.com>
Cc: DT304 <czyivan@aol.com>; Author <author@noreply.github.com>
Sent: Fri, Mar 23, 2018 1:45 am
Subject: Re: [Safecast/Safecast-Air] Unable to see my data? (#21)

—
You are receiving this because you authored the thread.
Reply to this email directly, view it on GitHub, or mute the thread.

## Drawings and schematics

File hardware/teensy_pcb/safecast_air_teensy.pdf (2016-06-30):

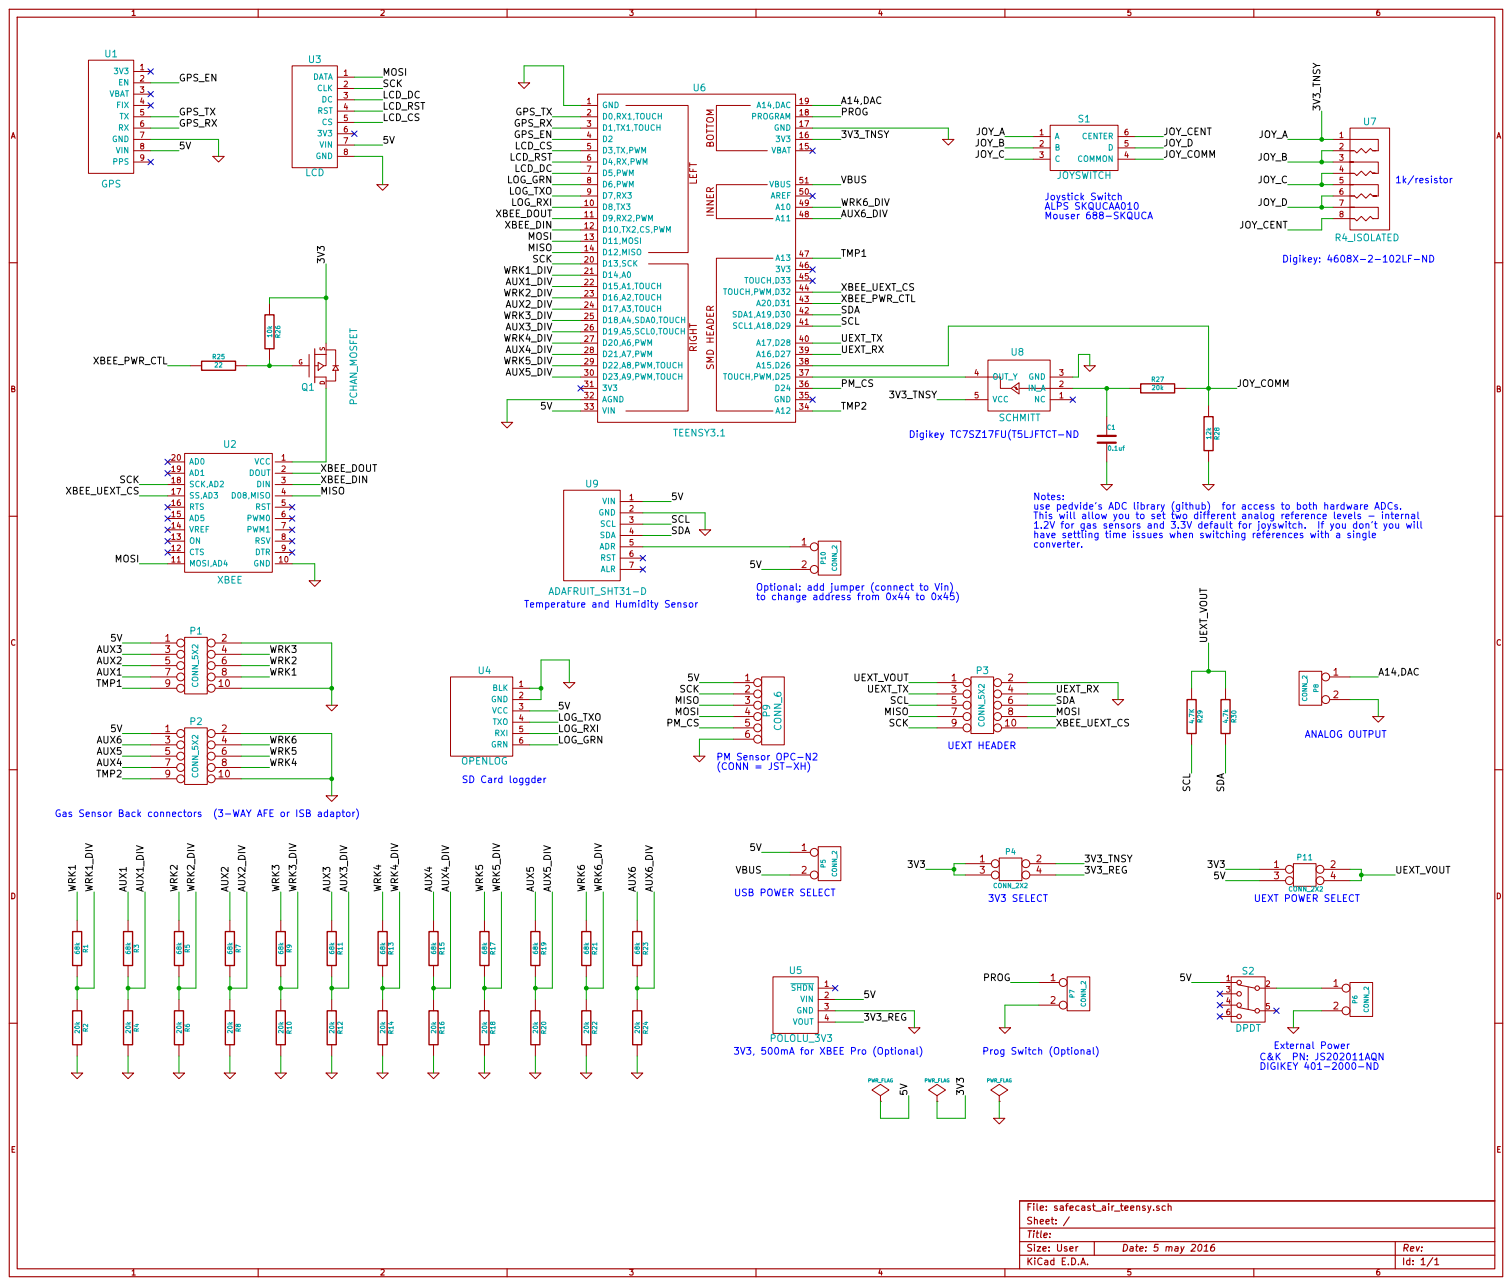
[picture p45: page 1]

to change address from 0x44 to 0x45) Temperature and Humidity Sensor D G

This will allow you to set two different analog reference levels - internal
1.2V for gas sensors and 3.3V default for joyswitch. If you don't you will

Optional: add jumper (connect to Vin)

3V3, 500mA for XBEE Pro (Optional)

Id: 1/1 Title: File: safecast_air_teensy.sch
Sheet: /

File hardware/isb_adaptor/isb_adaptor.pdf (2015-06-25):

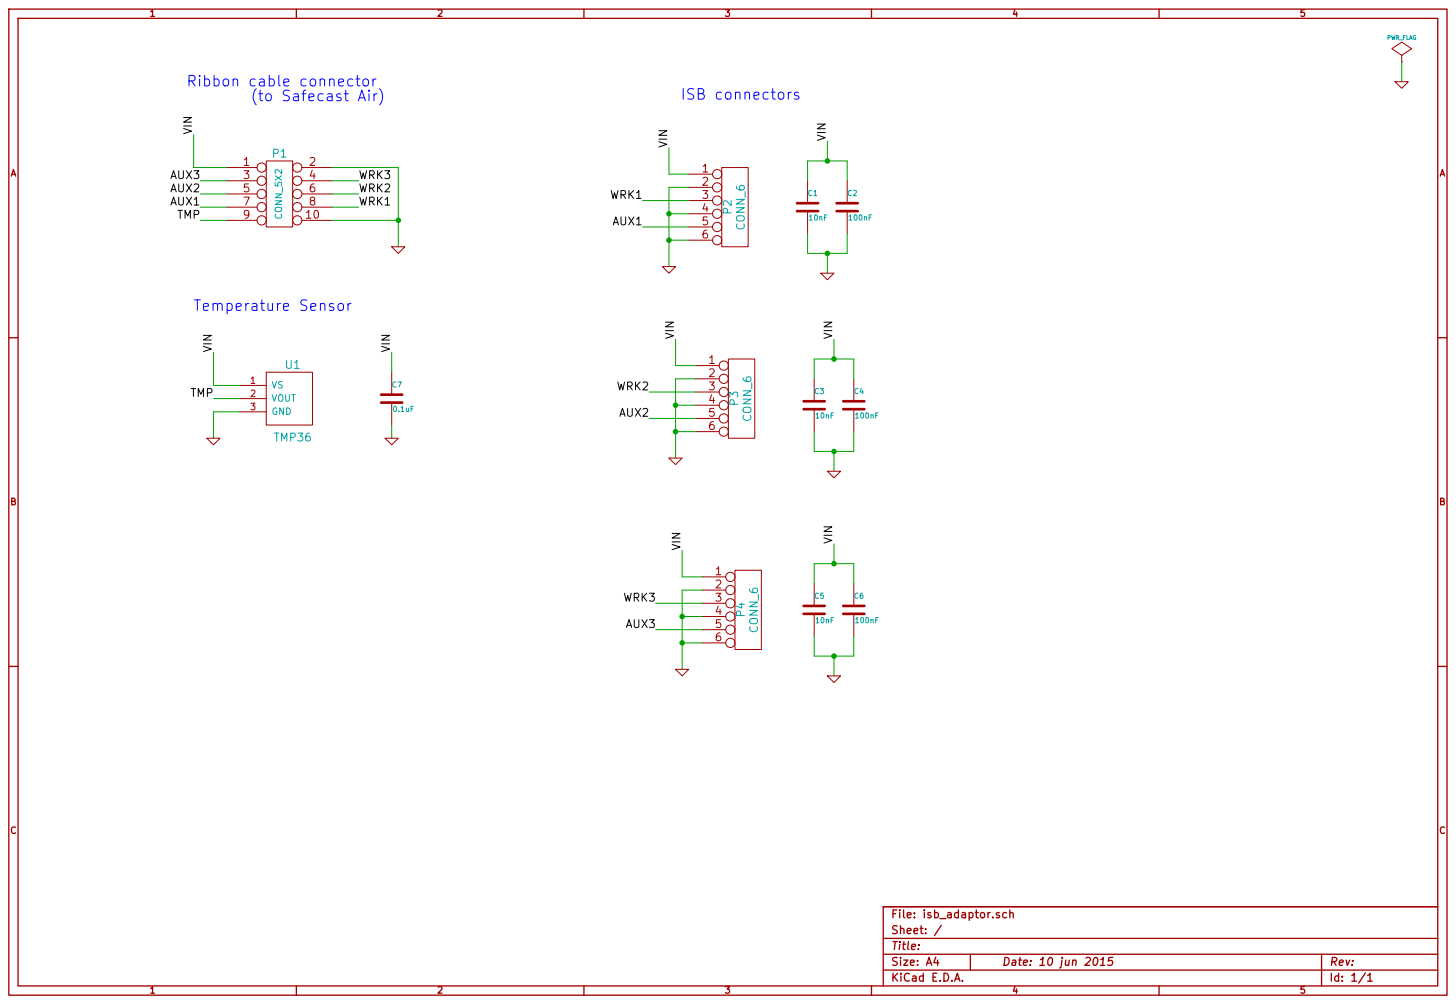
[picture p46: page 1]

Id: 1/1 Title: File: isb_adaptor.sch
Sheet: /

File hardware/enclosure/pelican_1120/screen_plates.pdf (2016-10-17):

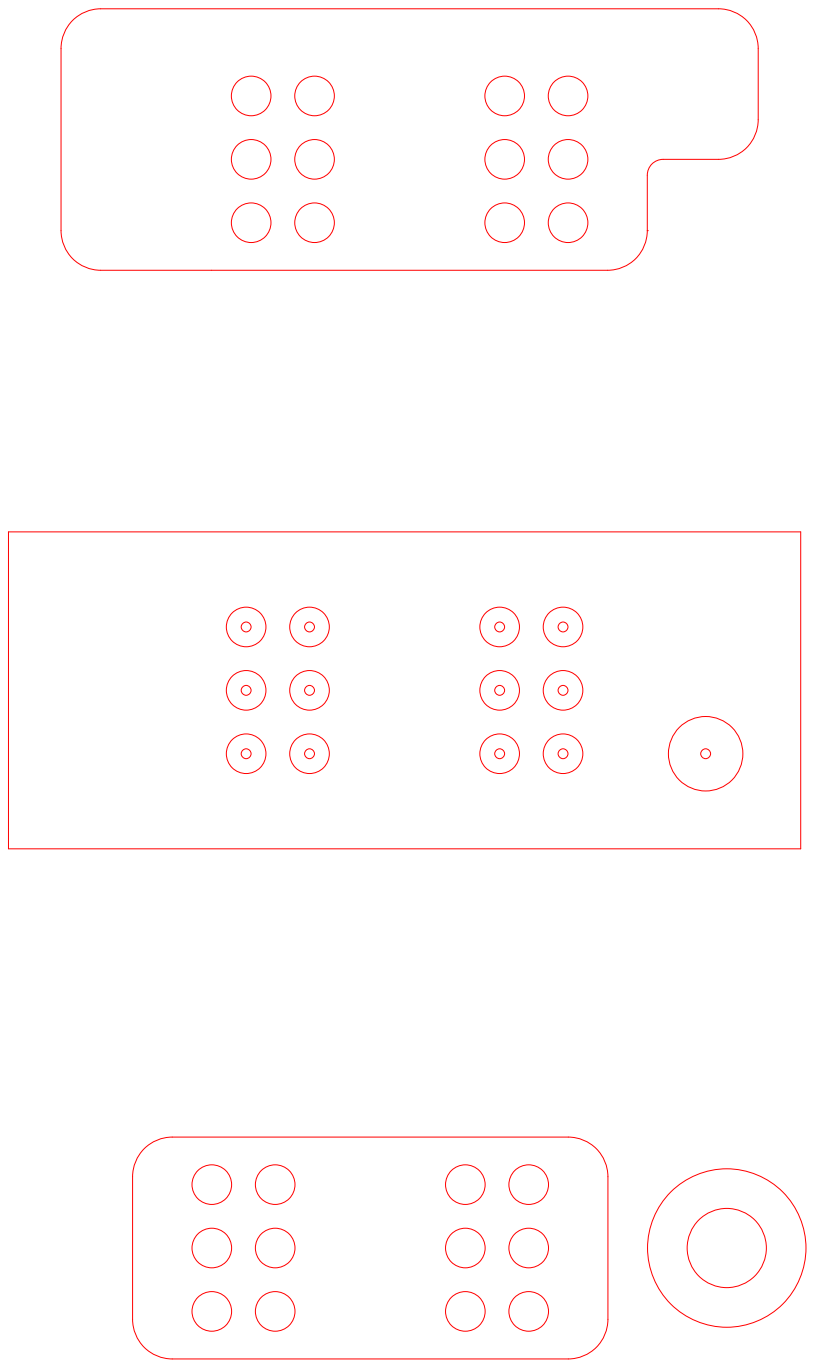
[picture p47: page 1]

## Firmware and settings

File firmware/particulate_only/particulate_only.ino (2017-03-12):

/*
   A Safecast device for Airquality measurement.

   Copyright (c) 2015, Will Dickson

   All rights reserved.

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
   THIS SOFTWARE IS PROVIDED BY THE COPYRIGHT HOLDERS AND CONTRIBUTORS "AS IS" AND
   ANY EXPRESS OR IMPLIED WARRANTIES, INCLUDING, BUT NOT LIMITED TO, THE IMPLIED
   WARRANTIES OF MERCHANTABILITY AND FITNESS FOR A PARTICULAR PURPOSE ARE
   DISCLAIMED. IN NO EVENT SHALL <COPYRIGHT HOLDER> BE LIABLE FOR ANY
   DIRECT, INDIRECT, INCIDENTAL, SPECIAL, EXEMPLARY, OR CONSEQUENTIAL DAMAGES
   (INCLUDING, BUT NOT LIMITED TO, PROCUREMENT OF SUBSTITUTE GOODS OR SERVICES;
   LOSS OF USE, DATA, OR PROFITS; OR BUSINESS INTERRUPTION) HOWEVER CAUSED AND
   ON ANY THEORY OF LIABILITY, WHETHER IN CONTRACT, STRICT LIABILITY, OR TORT
   (INCLUDING NEGLIGENCE OR OTHERWISE) ARISING IN ANY WAY OUT OF THE USE OF THIS
   SOFTWARE, EVEN IF ADVISED OF THE POSSIBILITY OF SUCH DAMAGE.

History:

Contact:
   
*/

#include <SPI.h>
#include <i2c_t3.h>
#include <Adafruit_GFX.h>
#include <Adafruit_SSD1306.h>
#include <Adafruit_GPS.h>
#include <Adafruit_SHT31.h>
#include <ArduinoJson.h>
#include <Time.h>
#include <TimeAlarms.h>
#include <EEPROM.h>
#include "constants.h"
#include "configuration.h"
#include "fixed_vector.h"
#include "opcn2.h"
#include "gps_monitor.h"
#include "openlog.h"
#include "logger.h"


Adafruit_SSD1306 display( constants::DisplayDC, constants::DisplayReset, constants::DisplayCS);
Openlog openlog(constants::DefaultOpenlogParam);
Configuration configuration(constants::ConfigurationFile,openlog);
GPSMonitor gpsMonitor;
OPCN2 particleCounter(constants::DefaultOPCN2Param, constants::DefaultOPCN2Ids);
Adafruit_SHT31 humidityAndTempSensor = Adafruit_SHT31();
Logger dataLogger(constants::DefaultLoggerParam,openlog);


void setupDisplay();
void loadConfiguration(); 
void showStartupScreen(); 
void setupGPSMonitor();
void setupParticleCounter();
void setupSHT31();
void setupDataLogger();
void showFirstReadingScreen();


void setup()
{
    // This is the magic trick for snprintf to support float
    asm(".global _snprintf_float");

    // USB Serial for debugging, etc.
    Serial.begin(constants::USBSerialBaudRate);

    Serial.println("begin setup");

    Serial.println("* display");
    setupDisplay();

    Serial.println("* openlog");
    openlog.initialize();

    Serial.println("* loadConfiguration");
    loadConfiguration();

    showStartupScreen();

    Serial.println("* gps");
    setupGPSMonitor();

    Serial.println("* particleCounter");
    setupParticleCounter();

    Serial.println("* SHT31");
    setupSHT31();

    Serial.println("* dataLogger");
    setupDataLogger();

    showFirstReadingScreen();

    Serial.println("setup complete");
}


void loop()
{
    Alarm.delay(constants::LoopDelay);
    gpsMonitor.update();
    dataLogger.update();
}


void setupDisplay()
{
    // Required or conflict with OLED display
    pinMode(constants::DefaultOPCN2Param.spiCsPin,OUTPUT);
    digitalWrite(constants::DefaultOPCN2Param.spiCsPin,HIGH);

    display.begin(SSD1306_SWITCHCAPVCC);
    SPI.beginTransaction(constants::DisplaySPISettings);
    display.clearDisplay();   
    display.display();
    display.setTextSize(1);
    display.setTextColor(WHITE);
    SPI.endTransaction();
}


void loadConfiguration()
{
    // Try to load configuration file
    bool ok = false;
    for (int i=0; (i<constants::NumLoadConfigTrys && !ok); i++)
    {
        SPI.beginTransaction(constants::DisplaySPISettings);
        display.clearDisplay();   
        display.setCursor(0,0);
        display.print("load config: ");
        display.println(i);
        display.display();
        SPI.endTransaction();

        ok = configuration.initialize();
        delay(10);
    }

    if (!ok)
    {
        // Failed to load configuration from SD card.
        SPI.beginTransaction(constants::DisplaySPISettings);
        display.clearDisplay();   
        display.setCursor(0,0);
        display.println("error: config file");
        display.println(configuration.errorMsg());
        display.display();
        SPI.endTransaction();
        while (true) {}  // Freeze here
    }
    else
    {
        SPI.beginTransaction(constants::DisplaySPISettings);
        display.clearDisplay();   
        display.setCursor(0,0);
        display.println("config file OK");
        display.display();
        SPI.endTransaction();
    }
    delay(1000);
}


void showStartupScreen()
{
    SPI.beginTransaction(constants::DisplaySPISettings);
    display.clearDisplay();   
    display.setCursor(0,0);
    display.print("Safecast Air V");
    display.println((constants::SoftwareVersion));
    display.print("Device Name=");
    display.println((constants::DeviceName));
    display.print("Device ID=");
    display.println(configuration.deviceId());
    display.display();
    SPI.endTransaction();
    delay(3000);
    SPI.beginTransaction(constants::DisplaySPISettings);
    display.clearDisplay();   
    display.setCursor(0,0);
    display.println("Initializing ... ");
    display.display();
    SPI.endTransaction();
}


void setupGPSMonitor()
{
    // Setup GPS monitor
    gpsMonitor.initialize();
    gpsMonitor.setTimerCallback( []() {gpsMonitor.readData(); });
    gpsMonitor.start();

    SPI.beginTransaction(constants::DisplaySPISettings);
    display.println("* gps");
    display.display();
    SPI.endTransaction();
}


void setupParticleCounter()
{
    // Setup particle counter
    particleCounter.initialize();
    particleCounter.setIds(configuration.opcn2Ids());
    bool status = particleCounter.checkStatus();
    bool laserAndFanOk = false;
    particleCounter.setFanAndLaserOn(&laserAndFanOk);

    SPI.beginTransaction(constants::DisplaySPISettings);
    display.print("* opcn2: ");
    display.print(status);
    display.print(",");
    display.println(laserAndFanOk);
    display.display();
    SPI.endTransaction();

}


void setupSHT31()
{
    // Setup humidity and temperature sensor
    bool status = humidityAndTempSensor.begin(constants::SHT31Address);
    SPI.beginTransaction(constants::DisplaySPISettings);
    display.print("* sht31: ");
    display.println(status);
    display.display();
    SPI.endTransaction();
}


void setupDataLogger()
{
    // Setup dataLogger timer
    bool loggerOk =  dataLogger.initializeFile();
    SPI.beginTransaction(constants::DisplaySPISettings);
    display.print("* log: ");
    display.println(loggerOk);
    display.display();
    SPI.endTransaction();
    delay(2000);
    Alarm.timerRepeat(dataLogger.logWritePeriod(), [](){dataLogger.writeLogOnTimer();});
    Alarm.timerRepeat(dataLogger.dataSamplePeriod(), [](){dataLogger.dataSampleOnTimer();} );

    // After starting timers take reading from particle sensor to clear out old histogram counts
    particleCounter.getHistogramData(); 

    // Setup wifly
    bool wifiOk = dataLogger.initializeWifi();

    SPI.beginTransaction(constants::DisplaySPISettings);
    if (wifiOk)
    {
        display.print("* ip: ");
        display.println(dataLogger.wifiIP());
    }
    else
    {
        display.print("* ");
        display.println(dataLogger.wifiErrorMsg());
    }
    display.display();
    SPI.endTransaction();
    delay(2000);
}


void showFirstReadingScreen()
{
    SPI.beginTransaction(constants::DisplaySPISettings);
    display.clearDisplay();
    display.setCursor(0,0);
    display.println();
    display.println("First reading  ... ");
    display.print("takes ");
    display.print(dataLogger.dataSamplePeriod());
    display.println(" seconds");
    display.display();
    SPI.endTransaction();
}

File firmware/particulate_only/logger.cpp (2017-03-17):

#include "logger.h"
#include "util/atomic.h"
#include <Adafruit_SSD1306.h>
#include <Adafruit_GPS.h>
#include <Adafruit_SHT31.h>
#include "constants.h"
#include "configuration.h"
#include "opcn2_ids.h"

extern Configuration configuration;
extern GPSMonitor gpsMonitor;
extern OPCN2 particleCounter;
extern Adafruit_SSD1306 display;
extern Adafruit_SHT31 humidityAndTempSensor; 

Logger::Logger(LoggerParam param, Openlog &openlog) : openlog_(openlog)
{
    param_ = param;
}


bool Logger::initializeFile()
{
    return openlog_.openNewLogFile();
}

bool Logger::initializeWifi()
{ 
    wifiOK_ = true;
    wifiErrorMsg_ = String("");

    pinMode(constants::DefaultWifiParam.pwrPin, OUTPUT);
    wifiTogglePower();

    wifi_ = ESP8266(*constants::DefaultWifiParam.serialPtr, constants::DefaultWifiParam.baudRate);

    if (!wifi_.setOprToStation()) 
    {
        wifiErrorMsg_ = String("err stat");
        wifiOK_= false;
        return wifiOK_;
    }

    if (!wifi_.joinAP(configuration.wifiSSID(), configuration.wifiPass()))
    {
        wifiErrorMsg_ = String("err join");
        wifiOK_= false;
        return wifiOK_;
    }

    if (!wifi_.disableMUX()) 
    {
        wifiErrorMsg_ = String("err mux");
        wifiOK_= false;
        return wifiOK_;
    }

    wifiIP_ = wifi_.getLocalIP();
    return wifiOK_; 
}


bool Logger::wifiOK()
{
    return wifiOK_;
}


void Logger::wifiPowerOn()
{
    digitalWrite(constants::DefaultWifiParam.pwrPin, LOW);
}

void Logger::wifiPowerOff()
{ 
    digitalWrite(constants::DefaultWifiParam.pwrPin, HIGH);
}


void Logger::wifiTogglePower()
{
    wifiPowerOff();
    delay(constants::DefaultWifiParam.pwrOffDelay);
    wifiPowerOn();
    delay(constants::DefaultWifiParam.pwrOnDelay);
}


String Logger::wifiIP()
{
    return wifiIP_;
}


String Logger::wifiErrorMsg()
{
    return wifiErrorMsg_;
}


unsigned long Logger::logWritePeriod()
{
    return param_.logWritePeriod;
}


unsigned long Logger::dataSamplePeriod()
{
    return param_.dataSamplePeriod;
}

void Logger::writeLogOnTimer()
{
    writeLogFlag_ = true;
    wifiSendUnitIndex_ = 0;
}


void Logger::dataSampleOnTimer()
{
    dataSampleFlag_ = true;
}


void Logger::update()
{
    if (dataSampleFlag_)
    {
        Serial.print("sample data ... ");
        opcn2Data_ = particleCounter.getHistogramData();
        humidity_ = humidityAndTempSensor.readHumidity(); 
        temperature_ =  humidityAndTempSensor.readTemperature();
        writeDisplay();
        dataSampleFlag_ = false;
        Serial.println("done");
    }
    if (writeLogFlag_)
    {
        Serial.print("write log ... ");
        writeLog();
        writeLogFlag_ = false;
        Serial.println("done");
    }
    wifiSendDataToServer();
}


void Logger::writeLog()
{

    OPCN2Ids opcn2Ids = particleCounter.getIds();

    // Get GPS position data
    gpsDataOk_ = false;
    if (gpsMonitor.haveData())
    {
        gpsData_ = gpsMonitor.getData(&gpsDataOk_);
    }
    if (!gpsDataOk_)
    {
        return;
    }
    String dateTimeString = gpsData_.getDateTimeString();
    String latitudeString = gpsData_.getLatitudeString();
    String longitudeString = gpsData_.getLongitudeString();

    // Create Json output data
    jsonBuffer_ = StaticJsonBuffer<JsonBufferSize>(); // Clear the buffer 
    JsonObject &rootObj = jsonBuffer_.createObject();
    rootObj["dev"] = constants::DeviceName.c_str();        
    String deviceId = configuration.deviceId();
    rootObj["id"]  = deviceId.c_str();              
    rootObj["msg"] = "dat";

    // Add GPS data
    JsonObject &gpsObj = rootObj.createNestedObject("gps");
    gpsObj["date"] = dateTimeString.c_str();
    gpsObj["lat"] = latitudeString.c_str();
    gpsObj["lon"] = longitudeString.c_str();
    gpsObj["alt"] = gpsData_.getAltitudeInMeter();
    gpsObj["spd"] = gpsData_.getSpeedInMeterPerSec();
    gpsObj["ang"] = gpsData_.angle;
    gpsObj["fix"] = gpsData_.fix;
    gpsObj["num"] = gpsData_.satellites;

    // Add OPN2 sensor  
    {
        JsonArray &pmArray = rootObj.createNestedArray("pm");
        JsonObject &opcn2Obj = pmArray.createNestedObject();
        opcn2Obj["pos"] = "norm";
        opcn2Obj["pm1"] = opcn2Data_.PM1;
        opcn2Obj["pm2_5"] = opcn2Data_.PM2_5;
        opcn2Obj["pm10"] = opcn2Data_.PM10;
        opcn2Obj["rate"] = opcn2Data_.flowRate;
        opcn2Obj["dt"] = opcn2Data_.samplePeriod;
        opcn2Obj["mtof1"] = opcn2Data_.bin1_mtof;
        opcn2Obj["mtof3"] = opcn2Data_.bin3_mtof;
        opcn2Obj["mtof5"] = opcn2Data_.bin5_mtof;
        opcn2Obj["mtof7"] = opcn2Data_.bin7_mtof;
        JsonArray &binCntArray = opcn2Obj.createNestedArray("cnt");
        for (int i=0; i<OPCN2Data::NumHistogramBins; i++)
        {
            binCntArray.add(opcn2Data_.binCount[i]);
        }

        JsonObject &idsObj = opcn2Obj.createNestedObject("ids");
        idsObj["pm1"] = opcn2Ids.pm1;
        idsObj["pm2_5"] = opcn2Ids.pm2_5;
        idsObj["pm10"] = opcn2Ids.pm10;
        idsObj["rate"] = opcn2Ids.rate;
        idsObj["dt"] = opcn2Ids.dt;
        idsObj["mtof1"] = opcn2Ids.mtof1;
        idsObj["mtof3"] = opcn2Ids.mtof3;
        idsObj["mtof5"] = opcn2Ids.mtof5;
        idsObj["mtof7"] = opcn2Ids.mtof7;
        JsonArray &cntIdsArray = idsObj.createNestedArray("cnt");
        for (int i=0; i<OPCN2Data::NumHistogramBins; i++)
        {
            cntIdsArray.add(opcn2Ids.cnt[i]);
        }
    }

    // Add temperature humidity sensor
    JsonObject &sht31Obj = rootObj.createNestedObject("sht31");
    sht31Obj["temp"] = temperature_;
    sht31Obj["humd"] = humidity_;
    JsonObject &sht31IdsObj = sht31Obj.createNestedObject("ids");
    sht31IdsObj["temp"] = configuration.sht31Ids().temperature; 
    sht31IdsObj["humd"] = configuration.sht31Ids().humidity;

    // Write json object to open log
    rootObj.printTo(*openlog_.getSerialPtr());
    openlog_.println();
}
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

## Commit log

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2014-11-17 Modified custom library component pin definitions (electrical type) in order to get a proper DRC.
    [safecast_air_teensy.sch]
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2014-11-24 Cleaned up silkscreen and added gerber files for version 0.1 revision 1.
    [safecast_air_teensy-B_Cu.gbl, safecast_air_teensy-B_Mask.gbs, safecast_air_teensy-B_SilkS.gbo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]
2014-11-24 Added missing silkscreen elements (5V VBUS) and PROG.
    [safecast_air_teensy-B_Cu.gbl, safecast_air_teensy-B_Mask.gbs, safecast_air_teensy-B_SilkS.gbo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]
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2015-04-28 Added header for PM 2.5 & PM 10 sensor. Adjusted silkscreen and spacing on gas sensor headers - to get rid on collision issue when using to gas sensor cables simultaneously. Rerouted board.
    [safecast_air_teensy.dsn, safecast_air_teensy.kicad_pcb, safecast_air_teensy.sch]
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2015-05-05 Fixed issue with how power scale factor was being applied.
    [constants.cpp]
2015-05-05 Fixed another issue with power scaling.
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2015-05-12 Fixed inverted sign in Occlusion sensor.
2015-05-12 Added notes about moving OccupancySensor elapsed time check from pin change callback to timer callback. Currently values won't update if not receiving regular pulses.
    [safecast_air.ino]
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2015-05-20 Removed TimerOne and TimerThree and replaced with IntervalTimer for scheduleing the PM Sensor and gas sensor timer callbacks.
    [constants.cpp, safecast_air.ino]
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2015-05-29 Re-arranged directory structure in preparation for merge with hardware and documentation repositories.
    rename : LICENSE => firmware/LICENSE
    rename : README.text => firmware/README.text
    rename : safecast_air/constants.cpp => firmware/safecast_air/constants.cpp
    rename : safecast_air/constants.h => firmware/safecast_air/constants.h
    rename : safecast_air/filter.cpp => firmware/safecast_air/filter.cpp
    rename : safecast_air/filter.h => firmware/safecast_air/filter.h
    rename : safecast_air/fixed_vector.h => firmware/safecast_air/fixed_vector.h
    rename : safecast_air/gas_sensor.cpp => firmware/safecast_air/gas_sensor.cpp
    rename : safecast_air/gas_sensor.h => firmware/safecast_air/gas_sensor.h
    r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
    [constants.cpp, constants.h, safecast_air.ino]
2015-05-29 Re-arrange directory structure in preparation for merge with firmware and documentation repositories.
    rename : 3X2_SHRD_HEADER.mod => hardware/3X2_SHRD_HEADER.mod
    rename : 4-40.mod => hardware/4-40.mod
    rename : 5X2_2MM_SHRD_HEADER.mod => hardware/5X2_2MM_SHRD_HEADER.mod
    rename : 5X2_SHRD_HEADER.mod => hardware/5X2_SHRD_HEADER.mod
    rename : 7X2_SHRD_HEADER.mod => hardware/7X2_SHRD_HEADER.mod
    rename : ADAFRUIT_128X64_OLED.mod => hardware/ADAFRUIT_128X64_OLED.mod
    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
    [safecast_air_teensy-B_Cu.gbl, safecast_air_teensy-B_Mask.gbs, safecast_air_teensy-B_SilkS.gbo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]
2015-05-29 Re-arranged directories a bit more. Added licenses.
    rename : docs/LICENSE => docs/sphinx/LICENSE
    rename : docs/Makefile => docs/sphinx/Makefile
    rename : docs/_static/logo.png => docs/sphinx/_static/logo.png
    rename : docs/_static/teensy_pcb_1.png => docs/sphinx/_static/teensy_pcb_1.png
    rename : docs/_static/teensy_pcb_2.png => docs/sphinx/_static/teensy_pcb_2.png
    rename : docs/_templates/LICENSE => docs/sphinx/_templates/LICENSE
    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
    [safecast_air_teensy-B_Cu.gbl, safecast_air_teensy-B_Mask.gbs, safecast_air_teensy-B_SilkS.gbo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]
2015-06-04 Worked on pcb revisions. Modified joystick switch so that it uses resistor ladder. This reduces number of required teensy pins from five to two - one analog input and one digital input.
    [safecast_air_teensy.sch]
2015-06-04 Added schmitt trigger to joyswitch (RC) debounce circuit. Modified debounce R ladder slightly so that it isn't always pulling current. Also, split joyswitch dio and ain inputs so that ain is pre RC f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
    [safecast_air_teensy.sch]
2015-06-10 Added header for opc-n2 particle counter. Changed pin used for pwm2 as d33 pin can't be low during reboot of teensy. Swapped with UEXT_CS. Removed optional shutdown for external 3v3 regulator - as pi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
    [safecast_air_teensy.dsn, safecast_air_teensy.kicad_pcb, safecast_air_teensy.sch]
2015-06-10 Rename pcb directory -> teensy_pcb in preparation for adding hardware/adapter sub-directory.
    rename : hardware/pcb/3X2_SHRD_HEADER.mod => hardware/teensy_pcb/3X2_SHRD_HEADER.mod
    rename : hardware/pcb/4-40.mod => hardware/teensy_pcb/4-40.mod
    rename : hardware/pcb/5X2_2MM_SHRD_HEADER.mod => hardware/teensy_pcb/5X2_2MM_SHRD_HEADER.mod
    rename : hardware/pcb/5X2_SHRD_HEADER.mod => hardware/teensy_pcb/5X2_SHRD_HEADER.mod
    rename : hardware/pcb/7X2_SHRD_HEADER.mod => hardware/teensy_pcb/7X2_SHRD_HEADER.mod
    rename : hardware/pcb/ADAFRUIT_128X64_OLED.mod => hardware/teensy_pcb/ADAFRUIT_128X64_OLED.mod
    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
    [safecast_air_teensy-B_Cu.gbl, safecast_air_teensy-B_Mask.gbs, safecast_air_teensy-B_SilkS.gbo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]
2015-06-10 Added design of adaptor PCB for alphasense ISB sensor boards. Provides the same interface (and connector) as the 3-way AFE. Also, includes a similar temperature sensor.
    [isb_adaptor.dsn, isb_adaptor.kicad_pcb, isb_adaptor.sch]
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2015-06-11 Re-made gerber files for v0.1 revision 3 of the safecast air teensy pcb. Required due to the resent design changes.
    [safecast_air_teensy-B_Cu.gbl, safecast_air_teensy-B_Mask.gbs, safecast_air_teensy-B_SilkS.gbo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]
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2015-06-11 Added some notes to schematic (and remade pdf) concerning using both hardware ADCs via pedvide's ACD library. This will allow you to simultaneously set two different analog input reference levels - o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
    [safecast_air_teensy.sch]
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2015-06-18 Modified connections to XBee socket so that is will work with LoRa modules which use the SPI connections rather than the UART. Added pull up resistors to UEXT I2C. Added 3.3V/5V selection jumper for 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
    [safecast_air_teensy.dsn, safecast_air_teensy.kicad_pcb, safecast_air_teensy.sch]
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2015-08-30 Modified faraday cage top - added additional holes for securing top screen.
    [faraday_top.dxf]
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2015-09-01 Fixed issue with potential outer boundary gouging on faraday cage abs gcode.
    [layout.dxf]
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2015-09-14 Added floor layout for enclosure.
    rename : hardware/enclosure/layouts/floor_layout.dxf => hardware/enclosure/layouts/old/floor_layout.dxf
    rename : hardware/enclosure/layouts/isb_adaptor.dxf => hardware/enclosure/layouts/old/isb_adaptor.dxf
    rename : hardware/enclosure/layouts/lid_layout.dxf => hardware/enclosure/layouts/old/lid_layout.dxf
    rename : hardware/enclosure/layouts/teensy_pcb.dxf => hardware/enclosure/layouts/old/teensy_pcb.dxf
    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
    [floor_layout.dxf, isb_adaptor.dxf]
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2015-12-14 Added mounting plates for small enclosure.
    rename : hardware/enclosure/faraday/BOM.txt => hardware/enclosure/large/faraday/BOM.txt
    rename : hardware/enclosure/faraday/cnc/abs_0p25in/boundary.ngc => hardware/enclosure/large/faraday/cnc/abs_0p25in/boundary.ngc
    rename : hardware/enclosure/faraday/cnc/abs_0p25in/boundary.py => hardware/enclosure/large/faraday/cnc/abs_0p25in/boundary.py
    rename : hardware/enclosure/faraday/cnc/abs_0p25in/fixture_drill.ngc => hardware/enclosure/large/faraday/cnc/abs_0p25in/fixture_drill.ngc
    rename : hardware/enclosure/faraday/cnc/abs_0p25in/fixture_drill.py => hardware/enclosure/large/faraday/cnc/abs_0p25in/fixture_drill.py
    rename : hardware/enclosure/farada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
    [bottom_layout.dxf, combined_template.dxf, faraday_floor.dxf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]
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2016-02-04 Fixed issue with sending json data via wifi - can now send full data message for methane sensor.
    [logger.cpp]
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2016-02-10 Modified methane version's display output for smaller display sizes. Added possible wifly reboot triggered by failure counter. Note, during the last couple days testing I've seen he wifly hang occass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
    [constants.cpp, logger.cpp, methane_test.ino]
2016-02-19 Re-organized enclosure files by brand and model names. Added parts for methane only seahorse 120 enclosure.
    rename : hardware/enclosure/large/faraday/BOM.txt => hardware/enclosure/budind_nema_nbb/faraday/BOM.txt
    rename : hardware/enclosure/large/faraday/cnc/abs_0p25in/boundary.ngc => hardware/enclosure/budind_nema_nbb/faraday/cnc/abs_0p25in/boundary.ngc
    rename : hardware/enclosure/large/faraday/cnc/abs_0p25in/boundary.py => hardware/enclosure/budind_nema_nbb/faraday/cnc/abs_0p25in/boundary.py
    rename : hardware/enclosure/large/faraday/cnc/abs_0p25in/fixture_drill.ngc => hardware/enclosure/budind_nema_nbb/faraday/cnc/abs_0p25in/fixture_drill.ngc
    rename : hardware/enclosure/large/faraday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
    [bottom_layout.dxf, combined_template.dxf, faraday_floor.dxf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]
2016-02-19 Added modified screen plate - for more surface area. Added pcb position adjustment plate - so right angle usb cable will fit with case closed.
    [position_adjust_plate.dxf]
2016-02-19 Added gcode for laser cutting pcb_adjust_plate.
    rename : hardware/enclosure/pelican_1120/position_adjust_plate.dxf => hardware/enclosure/pelican_1120/pcb_adjust_plate.dxf
    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
    [pcb_adjust_plate.dxf]
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2016-05-03 Started revision 4 changes. Added onboard temperature/humidity sensor. Diconnected D33 - moved UEXT/XBEE CS to D32. Removed header for Amphenol particulate sensor. Added digital line to switch power 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
    [safecast_air_teensy.sch]
2016-05-04 Added P-chan mosfet switch for power toggle of wifly/XBEE. Swapped out through hole resistors/capacitors for SM0805s. Added temperature/humidity sensor. Re-worked layout.
    [safecast_air_teensy.dsn, safecast_air_teensy.kicad_pcb, safecast_air_teensy.sch]
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2016-05-05 Fixed a few design rules and re-routed board.
    [safecast_air_teensy.dsn, safecast_air_teensy.kicad_pcb]
2016-05-05 Modified for upgrade to kicad 4. Added libs for schematic elements which missing/altered in new kicad version. Made schematic page size larger to accommodate different sheet style.
    [safecast_air_teensy.kicad_pcb, safecast_air_teensy.sch]
2016-05-05 Missed lib for old style capacitor - added.
    [safecast_air_teensy.sch]
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2016-05-20 Fixed issue with revision 4 BOM - R29 and R30 still had old through hole part number. Changed to 0805 resistors.
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2016-09-24 Fixed logging timer issue. Cleaned up OLED display output.
    [constants.cpp, constants.h, logger.cpp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]
2016-09-26 Finshed modifications for reading configuration from SD card (particulate_only). Also put sht31 and opcn2 sensors on a separate timer from logging. This is useful as the opcn2 sensor needs to be samp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
    [CONFIG.TXT, configuration.h]
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2016-09-26 Modified so that if configuration fails to load during startup the firmware will display and error message and stop. Modified load configuration so that it performs a couple of attempts before quitin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
    [constants.cpp, constants.h, particulate_only.ino]
2016-09-27 Added changes to startup sequence to try and fix issue initial config. file read fails on some setups.
    [constants.cpp, particulate_only.ino]
2016-09-27 Added hardware reset for openlog. Useful reseting during start up sequence and then waiting for prompt. This seems to eliminate start up problems - based on examples in sparkfun openlog repo.
    [constants.cpp, particulate_only.ino]
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2017-02-16 Fixed issue which resulted in low (and sometimes zero) PM readings. Issue was caused by call to setLaserAndFanOn in 'loop' used as temporary keep alive during development.
    [logger.cpp, particulate_only.ino]
2017-03-12 Modified how wifi data is sent to prevent delays/timeouts from wifi outagaes from effecting the timing of reads from the OPCN2 sensor.
    [logger.cpp, particulate_only.ino]
2017-03-17 Fixed issue with date format - changed formating from %d's to %02d's.
    [logger.cpp]
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
